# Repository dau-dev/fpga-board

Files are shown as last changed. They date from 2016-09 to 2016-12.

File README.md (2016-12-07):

# fpga-board
Based on the Xilinx AC701 and KC705 reference designs, this board was created to address the dearth of PCIe and DDR SODIMM capable board for less than $1000.

##Features
- Artix 7 FPGA (160k)
- 4GB DDR3 SODIMM
- 256MB Quad SPI Flash
- 8Kb IIC EEPROM
- SD Card Slot
- 2x 10/100/1000 Mbps Ethernet
- PCI Express 4 Lane
- Onboard JTAG
- Fixed Oscillator with differential 200MHz output
- User Programmable (IIC) Differential Oscillator (Range: 10MHz - 810 MHz, 156.250 MHz default)
- ATX Power 
- Half-Length PCI Card form factor

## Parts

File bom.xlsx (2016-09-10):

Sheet: Sheet2
Part | Value | Where?
R15 | 4.7k | U34 | 1/10W | 5%
C192 | 0.1uF | U34 | 25V | X5R
C30 | 0.1uF | U51 | 25V | X5R
R166 | 100 | U51 | 1/10W | 1%
L8 | Ferrite-220 | VDD_EPHYCLK | 2A
L9 | Ferrite-220 | GND_EPHYCLK | 2A
C190 | 0.01uF | VDD_EPHYCLK | 25V | X7R
C191 | 0.01uF | VDDA_EPHYCLK | 25V | X7R
C133 | 10uF | VDDA_EPHYCLK | 16V | X5R
R156 | 10 | VDD_EPHYCLK | 1/8W | 5%
C300 | 18pF | X3 | 50V | NPO
C301 | 18pF | X3 | 50V | NPO
R320 | 1.0M | X3 | 1/10W | 5%
R486 | 0 | U2 | 1/10W | 5%
R487 | 0 | U2 | 1/10W | 5%
R94 | 15 | U26 | 1/10W | 1%
R95 | 15 | U26 | 1/10W | 1%
R96 | 15 | U26 | 1/10W | 1%
C7 | 0.1uF | U19 | 25V | X5R
R429 | 15 | U67 | 1/10W | 1%
R430 | 15 | U67 | 1/10W | 1%
R19 | 4.7k | U67 | 1/10W | 5%
R21 | 4.7k | U67 | 1/10W | 5%
C18 | 0.1uF | U67 | 25V | X5R
R18 | 4.7k | U67 | 1/10W | 5%
R432 | 15 | U67 | 1/10W | 1%
R431 | 15 | U67 | 1/10W | 1%
R58 | 4.7k | U52 | 1/10W | 5%
R57 | 4.7k | U52 | 1/10W | 5%
R62 | 4.7k | U52 | 1/10W | 5%
R63 | 4.7k | U52 | 1/10W | 5%
R64 | 4.7k | U52 | 1/10W | 5%
R65 | 4.7k | U52 | 1/10W | 5%
R66 | 4.7k | U52 | 1/10W | 5%
R67 | 4.7k | U52 | 1/10W | 5%
R68 | 4.7k | U52 | 1/10W | 5%
R69 | 4.7k | U52 | 1/10W | 5%
R70 | 4.7k | U52 | 1/10W | 5%
R71 | 4.7k | U52 | 1/10W | 5%
R73 | 4.7k | U52 | 1/10W | 5%
R72 | 4.7k | U52 | 1/10W | 5%
C66 | 0.1uF | U52 | 25V | X5R
R54 | 4.7k | U52 | 1/10W | 5%
R55 | 4.7k | U52 | 1/10W | 5%
R244 | 4.7k | U52 | 1/10W | 5%
R59 | 4.7k | U52 | 1/10W | 5%
R60 | 4.7k | U52 | 1/10W | 5%
R61 | 4.7k | U52 | 1/10W | 5%
C1 | 0.1uF | U1 | 25V | X5R
C2 | 0.1uF | U1 | 25V | X5R
C163 | 100uF | U1 | 6.3 | X5R
R469 | 4.7k | U66
R306 | 261 | U66 | 1/10W | 1%
R307 | 261 | U66 | 1/10W | 1%
R396 | 261 | U1 | 1/10W | 1%
R339 | 1.21K | U1 | 1/10W | 1%
R338 | 1.21K | U1 | 1/10W | 1%
R337 | 1.21K | U1 | 1/10W | 1%
R83 | 4.7k | U1 | 1/10W | 5%
C462 | 0.1uF | U1 | 25V | X5R
C491 | 0.1uF | U1 | 25V | X5R
C463 | 0.1uF | U1 | 25V | X5R
C492 | 0.1uF | U1 | 25V | X5R
C158 | 100uF | U1 | 6.3 | X5R
C402 | 100uF | U1 | 6.3 | X5R
C461 | 0.1uF | U1 | 25V | X5R
C490 | 0.1uF | U1 | 25V | X5R
C157 | 100uF | U1 | 6.3 | X5R
R6 | 4.7k | J1 | 1/10W | 5%
R5 | 4.7k | J1 | 1/10W | 5%
R7 | 4.7k | J1 | 1/10W | 5%
R8 | 4.7k | J1 | 1/10W | 5%
C19 | 0.1uF | J1 | 25V | X5R
C17 | 0.1uF | J1 | 25V | X5R
C16 | 0.1uF | J1 | 25V | X5R
C15 | 0.1uF | J1 | 25V | X5R
C14 | 0.1uF | J1 | 25V | X5R
C13 | 0.1uF | J1 | 25V | X5R
C4 | 0.1uF | J1 | 25V | X5R
C3 | 0.1uF | J1 | 25V | X5R
C40 | 0.1uF | J1 | 25V | X5R
C39 | 0.1uF | J1 | 25V | X5R
C38 | 0.1uF | J1 | 25V | X5R
C37 | 0.1uF | J1 | 25V | X5R
C27 | 0.1uF | J1 | 25V | X5R
C26 | 0.1uF | J1 | 25V | X5R
C21 | 0.1uF | J1 | 25V | X5R
C20 | 0.1uF | J1 | 25V | X5R
C53 | 0.1uF | VTTDDR | 25V | X5R
C54 | 0.1uF | VTTDDR | 25V | X5R
C55 | 0.1uF | VTTDDR | 25V | X5R
C394 | 10uF | VTTDDR | 6.3V | X5R
C41 | 0.1uF | FPGA_1V5 | 25V | X5R
C42 | 0.1uF | FPGA_1V5 | 25V | X5R
C43 | 0.1uF | FPGA_1V5 | 25V | X5R
C393 | 10uF | FPGA_1V5 | 6.3V | X5R
C396 | 330uF | FPGA_1V5 | 10V | TANT
C51 | 0.1uF | VTTDDR | 25V | X5R
C50 | 0.1uF | VTTDDR | 25V | X5R
C46 | 0.1uF | VTTDDR | 25V | X5R
C392 | 10uF | VTTDDR | 6.3V | X5R
C386 | 0.01uF | VTTVREF | 25V | X7R
C155 | 100uF | U1 | 6.3 | X5R
R325 | 51.1K | U29 | 1/10W | 1%
R319 | 51.1K | U29 | 1/10W | 1%
R322 | 51.1K | U29 | 1/10W | 1%
R321 | 51.1K | U29 | 1/10W | 1%
R323 | 51.1K | U29 | 1/10W | 1%
R318 | 51.1K | U29 | 1/10W | 1%
R324 | 51.1K | U29 | 1/10W | 1%
R317 | 51.1K | U29 | 1/10W | 1%
C52 | 0.1uF | U29 | 25V | X5R
L12 | Ferrite-220 | VCC1V8
C400 | 4.7uF | VCC1V8_FILT | 10V | X5R
C90 | 0.1uF | VCC1V8_FILT | 25V | X5R
C398 | 4.7uF | VCC1V8_FILT | 10V
C86 | 0.1uF | VCC1V8_FILT | 25V
C87 | 0.1uF | VCC1V8_FILT | 25V
C85 | 0.1uF | VCC1V8_FILT | 25V
C84 | 0.1uF | VCC1V8_FILT | 25V
C88 | 0.1uF | VCC1V8_FILT | 25V
C83 | 0.1uF | VCC1V8_FILT | 25V
C397 | 4.7uF | VCC1V8_FILT | 10V
C81 | 0.1uF | VCC1V8_FILT | 25V
C82 | 0.1uF | VCC1V8_FILT | 25V
C80 | 0.1uF | VCC1V8_FILT | 25V
C79 | 0.1uF | VCC1V8_FILT | 25V
C89 | 0.1uF | VCC1V8_FILT | 25V
C64 | 0.1uF | VCC1V8_FILT | 25V
C403 | 4.7uF | VCC1V8 | 10V
C98 | 0.1uF | VCC1V8 | 25V
C99 | 0.1uF | VCC1V8 | 25V
C97 | 0.1uF | VCC1V8 | 25V
C96 | 0.1uF | VCC1V8 | 25V
C100 | 0.1uF | VCC1V8 | 25V
R271 | 1.00K | U12 | 1/16W
R274 | 1.00K | U12 | 1/16W
R272 | 1.00K | U12 | 1/16W
R273 | 1.00K | U12 | 1/16W
R2 | 4.7k | U12 | 1/10W
R291 | 4.99K | U12 | 1/10W
R1 | 4.7k | U12 | 1/10W
C56 | 0.1uF | U12 | 25V
C395 | 1000pF | U12 | 50V
R448 | 100 | U12 | 1/10W | 1%
R449 | 100 | U12 | 1/10W | 1%
R447 | 100 | U12 | 1/10W | 1%
R445 | 100 | U12 | 1/10W | 1%
R443 | 100 | U12 | 1/10W | 1%
R438 | 100 | U12 | 1/10W | 1%
R450 | 100 | U12 | 1/10W | 1%
R451 | 100 | U12 | 1/10W | 1%
R446 | 100 | U12 | 1/10W | 1%
R444 | 100 | U12 | 1/10W | 1%
R442 | 100 | U12 | 1/10W | 1%
R441 | 100 | U12 | 1/10W | 1%
R281 | 261 | U12 | 1/10W
R280 | 261 | U12 | 1/10W
R279 | 261 | U12 | 1/10W
C405 | 18pF | X1 | 50V | NPO
C406 | 18pF | X1 | 50V | NPO
C401 | 4.7k | U12 | 10V
C93 | 0.1uF | U12 | 25V
C94 | 0.1uF | U12 | 25V
C92 | 0.1uF | U12 | 25V
C91 | 0.1uF | U12 | 25V
C95 | 0.1uF | U12 | 25V
L10 | Ferrite-220 | X6
C281 | 330uF | X6 | 10V | TANT
C328 | 10uF | X6 | 16V | X5R
R167 | 100 | U24 | 1/10W | 1%
C33 | 0.1uF | U24 | 25V | X5R
C34 | 0.1uF | U24 | 25V | X5R
R292 | 4.7k | U24 | 1/10W | 5%
R4 | 4.7k | U24 | 1/10W | 5%
R16 | 4.7k | U24 | 1/10W | 5%
R490 | 0 | U24 | 1/10W | 5%
R491 | 0 | U24 | 1/10W | 5%
R488 | 0 | U24 | 1/10W | 5%
R489 | 0 | U24 | 1/10W | 5%
C173 | 1uF | SI5324_VCC | 25V | X5R
C35 | 0.1uF | SI5324_VCC | 25V | X5R
C36 | 0.1uF | SI5324_VCC | 25V | X5R
C156 | 100uF | U1 | 6.3 | X5R
C159 | 100uF | U1 | 6.3 | X5R
C57 | 0.1uF | U5 | 25V | X5R
C58 | 0.1uF | U5 | 25V | X5R

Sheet: Sheet3
Item# | Qty | Ref Des | Device | Package | Value | Voltage | Tolerance | Dielectric | Power | Manf | Manf P/N | Dist | Dist P/N | Alternate P/N
1 | 1 | B1 | Battery Slot |  | TS518FE-FL35E |  |  |  |  | SEIKO | TS518FE-FL35E | SEIKO | TS518FE-FL35E
2 | 174 | C1,C2,C3,C4,C7,C8,C13,C14,C15,C16,C17,C18,C19,C20,C21,C22,C23,C26,C27,C30,C33,C34,C35,C36,C37,C38,C39,C40,C41,C42,C43,C44,C45,C46,C47,C48,C49,C50,C51,C52,C53,C54,C55,C56,C57,C58,C59,C60,C61,C62,C63,C64,C66,C67,C68,C69,C70,C71,C72,C73,C74,C75,C76,C77,C78,C79,C80,C81,C82,C83,C84,C85,C86,C87,C88,C89,C90,C91,C92,C93,C94,C95,C96,C97,C98,C99,C100,C105,C106,C107,C108,C109,C110,C111,C112,C113,C116,C117,C118,C119,C120,C121,C122,C123,C124,C125,C126,C127,C128,C129,C130,C131,C132,C134,C135,C136,C137,C138,C139,C140,C141,C142,C143,C144,C145,C146,C147,C148,C149,C162,C164,C165,C166,C170,C171,C178,C180,C183,C187,C192,C193,C195,C239,C255,C264,C286,C295,C305,C311,C318,C320,C321,C322,C461,C472,C473,C480,C491,C492,C504,C505,C506,C507,C508,C509,C510,C511,C512,C516,C520,C526,C527,C528,C529 | Capacitor | 0402 | 0.1UF | 25V | 10% | X5R |  | Taiyo | TMK105BJ104KV-F | Digikey | 587-1456-2-ND
3 | 2 | C65,C252 | Capacitor | 0805 | 10UF | 10V | 10% | X5R |  | Murata | GRM219R61A106KE44D | Digikey | 490-4735-2-ND | GRM21BR61A106KE19L
4 | 7 | C101,C102,C103,C104,C462,C463,C490 | Capacitor | 0402 | 0.1UF | 25V | 10% | X5R |  | Taiyo | TMK105BJ104KV-F | Digikey | 587-1456-2-ND
5 | 2 | C114,C115 | Capacitor | 1206 | 22UF | 25V | 10% | X5R |  | Murata | GRM31CR61E226KE15L | Digikey | 490-5527-1-ND
6 | 20 | C133,C263,C265,C266,C267,C271,C328,C334,C335,C336,C337,C338,C339,C497,C498,C499,C500,C501,C502,C503 | Capacitor | 1206 | 10UF | 16V | 20% | X5R |  | TDK | C3216X5R1C106M | Digikey | 445-1426-2-ND
7 | 2 | C150,C151 | Capacitor | 0402 | 0.022UF | 10V | 10% | X5R |  | Kemet | C0402C223K8PACTU | Digikey | 399-3015-2-ND
8 | 34 | C152,C153,C353,C354,C355,C356,C357,C358,C359,C360,C361,C362,C363,C364,C365,C366,C371,C372,C373,C374,C376,C377,C378,C379,C380,C381,C387,C388,C389,C390,C391,C484,C485,C488 | Capacitor | 0402 | 4.7UF | 6.3V | 20% | X5R |  | TDK | C1005X5R0J475M | Mouser | 810-C1005X5R0J475M
9 | 14 | C154,C268,C269,C270,C395,C483,C493,C495,C496,C521,C523,C525,C553,C554 | Capacitor | 0402 | 1000PF | 50V | 10% | X7R |  | Panasonic | ECJ-0EB1H102K | Digikey | PCC1721TR-ND
10 | 17 | C155,C156,C157,C158,C159,C160,C161,C163,C317,C399,C402,C418,C421,C422,C517,C530,C531 | Capacitor | 1206 | 100UF | 6.3 | 20% | X5R |  | TAIYO YUDEN | JMK316BJ107ML-T | Digikey | 587-1963-2-ND
11 | 11 | C167,C168,C169,C173,C174,C175,C176,C177,C514,C515,C804 | Capacitor | 0603 | 1UF | 25V | 10% | X5R |  | MURATA | GRM188R61E105KA12D | Digikey | 490-3897-2-ND
12 | 11 | C172,C179,C182,C184,C185,C186,C253,C254,C262,C313,C513 | Capacitor | 1206 | 10UF | 25V | 20% | X5R |  | Taiyo | TMK316BJ106KL-T | Digikey | 587-1337-2-ND | GRM31CR61E106KA12L
13 | 61 | C181,C213,C214,C215,C216,C220,C221,C222,C223,C224,C225,C227,C229,C230,C240,C241,C242,C243,C244,C245,C246,C247,C248,C249,C250,C251,C256,C257,C258,C259,C260,C261,C272,C273,C274,C275,C276,C277,C278,C279,C280,C282,C283,C284,C285,C293,C294,C296,C307,C308,C309,C310,C312,C314,C315,C323,C324,C326,C327,C382,C383 | Capacitor | 1206 | 47UF | 25V | 10% | X5R |  | TDK | C3216X5R1E476M | Digikey | 445-8047-2-ND
14 | 38 | C188,C189,C190,C191,C201,C202,C203,C204,C205,C206,C207,C208,C209,C210,C211,C325,C386,C482,C518,C519,C532,C533,C534,C535,C536,C537,C538,C540,C541,C542,C543,C544,C545,C546,C547,C548,C549,C550 | Capacitor | 0402 | 0.01UF | 25V | 10% | X7R |  | Kemet | C0402C103K3RACTU | Digikey | 399-1278-2-ND
15 | 6 | C194,C196,C292,C319,C551,C552 | Capacitor | 0402 | 1UF | 16V | 10% | X5R |  | TDK | C1005X5R1C105K | Digikey | 445-4978-2-ND
16 | 5 | C197,C198,C199,C200,C212 | Capacitor | 1206 | 100UF | 6.3V | 20% | X5R |  | TAIYO YUDEN | JMK316BJ107ML-T | Digikey | 587-1963-2-ND
17 |  | C217,C218 | Capacitor | 0402 | DNP | DNP | DNP | DNP |  | NA | NA | DNP | DNP
18 | 1 | C219 | Capacitor | 2917 | 47UF | 25V | 20% | TANT_POLY |  | AVX | TCJD476M025R0100 | Digikey | 478-6638-2-ND
19 | 3 | C226,C228,C494 | Capacitor | 0805 | 4.7UF | 25V | 10% | X5R |  | Taiyo | TMK212BJ475KG-T | Digikey | 587-1782-2-ND
20 | 8 | C231,C232,C233,C234,C235,C236,C237,C238 | Capacitor | 0402 | 0.22UF | 16V | 10% | X5R |  | TDK | C1005X5R1C224K | Digikey | 445-4972-2-ND
21 | 2 | C281,C396 | Capacitor | TANT_D | 330UF | 10V | 10% | TANT |  | KEMET | T495D337K010ATE125 | Digikey | 399-3884-2-nd | TAJD337K010RNJ
22 | 10 | C287,C288,C289,C290,C291,C297,C298,C299,C302,C303 | Capacitor | 0805 | 47UF | 6.3V | 20% | X5R |  | Kemet | C0805C476M9PACTU | Digikey | 399-5506-2-ND | JMK212BJ476MG-T
23 | 4 | C300,C301,C405,C406 | Capacitor | 0402 | 18PF | 50V | 5% | NPO |  | Murata | GRM1555C1H180JZ01D | Digikey | 490-1281-2-ND | ECU-E1H180JCQ
24 | 9 | C304,C306,C384,C385,C474,C475,C478,C479,C481 | Capacitor | 1210 | 22UF | 25V | 10% | X5R |  | MURATA | GRM32ER61E226KE15L | Digikey | 490-3889-2-ND
25 |  | C329,C330,C331,C332,C333,C340,C341,C342,C343,C344,C345,C346,C347,C348,C349,C350,C351,C352 | Capacitor | C402_25 | DNP | 25V | 10% | X5R |  | TAIYO YUDEN | TMK105BJ104KV-F | DNP | DNP
26 | 5 | C367,C368,C369,C370,C375 | Capacitor | 0402 | 4.7UF | 6.3V | 20% | X5R |  | TDK | C1005X5R0J475M | Mouser | 810-C1005X5R0J475M
27 | 3 | C392,C393,C394 | Capacitor | 0805 | 10UF | 6.3V | 20% | X5R |  | Murata | GRM21BR60J106ME19L | Digikey | 490-1718-2-ND | ECJ-2FB0J106M
28 | 5 | C397,C398,C400,C401,C403 | Capacitor | 0603 | 4.7UF | 10V | 10% | X5R |  | TAIYO | LMK107BJ475KA-T | Digikey | 587-1441-2-ND | C1608X5R1A475K
29 | 1 | C407 | Capacitor | TANT_E | 680UF | 6.3V | 10% | TANT |  | AVX | TAJE687K006RNJ | Digikey | 478-2349-2-ND
30 | 48 | C408,C409,C410,C411,C412,C413,C414,C415,C416,C417,C419,C420,C425,C428,C429,C430,C431,C432,C434,C435,C436,C437,C438,C439,C440,C441,C442,C443,C445,C446,C447,C450,C451,C454,C455,C456,C457,C458,C459,C460,C464,C465,C466,C467,C468,C469,C470,C471 | Capacitor | 0402 | 0.47UF | 10V | 10% | X5R |  | Murata | GRM155R61A474KE15D | Digikey | 490-3264-1-ND
31 | 2 | C423,C424 | Capacitor | 0402 | 10PF | 50V | 5% | NP0 |  | Panasonic | ECJ-0EC1H100D | Digikey | PCC100CQTR-ND
32 | 8 | C426,C427,C433,C444,C448,C449,C452,C453 | Capacitor | 0402 | 0.47uF | 10V | 10% | X5R |  | Murata | GRM155R61A474KE15D | Digikey | 490-3264-1-ND
33 | 1 | C489 | Capacitor | 0402 | 2200PF | 25V | 10% | X7R |  | KEMET | C0402C222K3RACTU | Digikey | 399-1033-1-ND
34 | 2 | C486,C487 | Capacitor | 0805 | 100PF | 500V | 5% | NP0 |  | KEMET | C0805C101JCGACTU | Digikey | 399-5102-2-ND
35 | 2 | C522,C524 | Capacitor | 0402 | 3300PF | 25V | 10% | X7R |  | Panasonic | ECJ-0EB1E332K | Digikey | PCC332BQCT-ND
36 | 1 | C539 | Capacitor | CAP_F | 330UF | 25V | 20% | ELEC |  | Panasonic | EEE-FK1E331P | Digikey | PCE3803TR-ND
37 | 2 | C555,C556 | Capacitor | 0805 | 100UF | 6.3V | 20% | TANT |  | AVX | TLJP107M006R5400 | Digikey | 478-5260-2-ND
38 |  | CBL1 | PCIE Adapter Cable | MECH_PCIE_ADAPTER_CABLE | DNP |  |  |  |  | ANY | ANY | ANY | ANY
39 | 0 | CBL2 | Cable |  | PC_POWER_CABLE |  |  |  |  | AdamTech | PC-0102060AC03 | Mouser | 737-PC-0102060AC03
40 | 0 | CBL3 | Cable |  | USB_MINIB_CABLE |  |  |  |  | Qualtek | 3021009-06 | Mouser | 562-3021009-06
41 | 0 | CBL4 | Cable |  | USB_MICRO_CABLE |  |  |  |  | ASSMANN | AK67421-2-R | Digikey | AE10342-ND
42 | 1 | CG1 | I/O Cage | 74754-0101 | 74754-0101 |  |  |  |  | MOLEX | 74754-0101 | MOLEX | 74754-0101
43 | 9 | CP1,CP2,CP3,CP4,CP5,CP6,CP7,CP8,CP9 | Capacitor Array | 0805_A4 | 0.1UF | 10V | 20% | X5R |  | PANASONIC-ECG | ECJ-TVB1A104M | Digikey | 587-1046-2-ND
44 | 5 | D1,D2,D3,D4,D7 | Diode | DIO_CASE017AA_01 | 1N5335BRLG | 3.9V |  |  | 320MA | ON SEMICONDUCTOR | 1N5335BRLG | Digikey | 1N5335BRLGOSCT-ND
45 | 1 | D5 | Diode | DIO_DFS1150_7 | DFLS1150 | 820MV |  |  |  | Diodes Inc | DFLS1150-7 | Digikey | DFLS1150DICT-ND
46 | 1 | D6 | Diode | SOT_23 | BAS40-04 | 40V |  |  | 200MW | MICRO COMMERCIAL | BAS40-04-TP | Digikey | BAS40-04TPMSCT-ND
47 | 1 | D14 | Diode | MINIMELF | DL4148 | 100V |  |  | 460MW | MCC | DL4148-TP | Digikey | DL4148-TPMSCT-ND
48 | 1 | D15 | Diode | SOD_323F_REV | MM3Z2V7B | 2.7V | 2% |  | 460MW | Fairchild | MM3Z2V7B | Digikey | MM3Z2V7BCT-ND
49 | 1 | DIMMCAGE1 | SODIMM_CAGE |  | SODIMM_CAGE |  |  |  |  | LEADER TECH | 20S-CBSFNSV-1.50X3.0X0.35 | LEADER TECH | 20S-CBSFNSV-1.50X3.0X0.35
50 | 4 | DP1,DP2,DP3,DP4 | Diode | RCLAMP0524P | RCLAMP0524P | 15V |  | DIEL |  | Semtech | RCLAMP0524P.TCT | Digikey | RCLAMP0524PCT-ND
51 | 1 | DS1 | LED |  | LED-GRN-RED | 2.0V |  |  | 2.0-20MA | AVAGO | HSMF-C155 | Digikey | 516-1456-1-ND
52 | 14 | DS2,DS3,DS4,DS5,DS6,DS10,DS11,DS12,DS13,DS14,DS20,DS22,DS23,DS27 | LED |  | LED-GRN-SMT | 2.2V |  |  | 2.2-20MA | Lumex | SML-LX0603GW-TR | Digikey | 67-1549-2-ND
53 | 9 | DS15,DS16,DS17,DS18,DS19,DS21,DS24,DS25,DS26 | LED |  | LED-GRN-SMT | 2.2V |  |  |  | LUMEX | SML-LX0603GW | Digikey | 67-1549-2-ND
54 | 1 | J1 | Connector |  | DDR3_SO-DIMM_SHIELDED |  |  |  |  | Foxconn | AS0A626-U2SN-7F | Foxconn | AS0A626-U2SN-7F
55 | 1 | J2 | Connector | 2X5 | HDR_BOX_2X5 |  |  |  |  | Assmann | AWHW10G-0202-T-R | Digikey | HRP10H-ND
56 | 10 | J3,J5,J6,J8,J9,J10,J11,J52,J53,J63 | Header | 1X2 | HDR_1X2 |  |  |  |  | Sullins | PBC36SAAN | Digikey | S1011E-36-ND
57 | 1 | J4 | Connector |  | 87832-1420 |  |  |  |  | Molex | 87832-1420 | Digikey | WM18641-ND
58 | 1 | J7 | Header | 1X9 | HDR_1X9 |  |  |  |  | Sullins | PBC36SAAN | Digikey | S1011E-36-ND
59 | 1 | J12 | Header | 2X2 | HDR_2X2 |  |  |  |  | Sullins | PBC36DAAN | Digikey | S2011E-36-ND
60 | 1 | J17 | Connector |  | CONN_USB_MINI_B_TH |  |  |  |  | Molex | 54819-0589 | Mouser | 538-54819-0589
61 | 1 | J19 | Connector |  | TST-110-01-G-D |  |  |  |  | Samtec | TST-110-01-G-D | Samtec | TST-110-01-G-D
62 | 3 | J20,J21,J22 | Header | 1X1 | HDR_1X1 |  |  |  |  | Sullins | PBC36SAAN | Digikey | S1011E-36-ND
63 | 1 | J23 | Header | 2X7 | HDR_2X7 |  |  |  |  | Samtec | MTLW-107-07-G-D-265 | Digikey | S2011E-36-ND
64 |  | J24 | Header | 1X2 | DNP |  |  |  |  | SULLINS | PBC36SAAN | DNP | DNP
65 | 10 | J25,J26,J31,J32,J33,J34,J44,J45,J46,J47 | Connector |  | 32K10K-400L5 |  |  |  |  | Rosenberger | 32K10K-400L5 | Rosenberger | 32K10K-400L5
66 | 2 | J28,J29 | Test Points |  | BLACK |  |  |  |  | Keystone | 5001 | Digikey | 5001K-ND
67 | 1 | J30 | Connector |  | ASP_134486_01 |  |  |  |  | Samtec | ASP_134486_01 | Samtec | ASP-134486-01
68 | 8 | J35,J36,J37,J38,J39,J42,J43,J54 | Header | 1X3 | HDR_1X3 |  |  |  |  | Sullins | PBC36SAAN | Digikey | S1011E-36-ND
69 | 2 | J40,J41 | Test Points |  | YELLOW |  |  |  |  | Keystone | 5004 | Digikey | 5004K-ND
70 | 1 | J48 | Header | 1X6 | HDR_1X6 |  |  |  |  | Sullins | PBC36SAAN | Digikey | S1011E-36-ND
71 | 1 | J49 | Connector |  | 39-30-1060 |  |  |  |  | Molex | 39-30-1060 | Digikey | WM1353-ND
72 | 1 | J61 | Connector |  | 22_11_2032 |  |  |  |  | Molex | 22-11-2032 | Digikey | WM2701-ND
73 | 5 | L1,L2,L3,L4,L5 | Ferrite Chip | 0805 |  |  |  |  |  | Laird | HZ0805E601R-10 | Digikey | 240-2399-2-ND
74 | 2 | L6,L7 | Inductor | IND_IHLP2020BZ_ER |  |  |  |  |  | Vishay | IHLP2020BZER4R7M11 | Digikey | 541-1222-1-ND
75 | 15 | L8,L9,L10,L11,L12,L13,L14,L15,L16,L17,L18,L19,L20,L21,L22 | Ferrite Chip | 0603 |  |  |  |  |  | TDK | MPZ1608S221A | Digikey | 445-1565-2-ND
76 | 9 | L24,L25,L26,L27,L28,L29,L30,L31,L32 | Inductor | 2773021447 |  |  |  |  |  | FAIR-RITE | 2773021447 | Mouser | 623-2773021447LF
77 | 1 | LCD1 | Display |  | LCD_DISPLAY_16X2 |  |  |  |  | DisplayTech | S162D BA BC | DisplayTech | S162D BA BC
78 | 1 | LCD1_J11 | Connector | SAMTEC_SLW_107_01_G_D | SLW-107-01-G-D |  |  |  |  | Samtec | SLW-107-01-G-D | Samtec | SLW-107-01-G-D
79 |  | MH1,MH2,MH3,MH4,MH5,MH6 | Mounting Hole |  | DNP |  |  |  |  | DNP | DNP | DNP | DNP
80 |  | MH7,MH8,MH9 | Mounting Hole |  | DNP |  |  |  |  | DNP | DNP | DNP | DNP
81 | 15 | MJB1,MJB2,MJB3,MJB4,MJB5,MJB6,MJB7,MJB8,MJB9,MJB10,MJB11,MJB12,MJB13,MJB14,MJB15 | Shunt |  | JUMPER_BLOCK_2-PIN |  |  |  |  | ADAMTECH | MSDA-G | Digikey | S9002-ND
82 | 1 | MMD1 | Memory | DDR3_SODIMM | DDR3_SODIMM |  |  |  |  | MICRON | MT8JTF12864HZ-1G6G1 | Edge | MT8JTF12864HZ-1G6G1
83 | 6 | MRB1,MRB2,MRB3,MRB4,MRB5,MRB6 | Bumper |  | RUBBER_BUMPER |  |  |  |  | Keystone | 720 | Digikey | 720K-ND
84 | 12 | MS1,MS2,MS3,MS4,MS5,MS6,MS13,MS14,MS15,MS16,MS17,MS18 | Screws |  | MACHINE_SCREW_4-40 |  |  |  |  | ANY | ANY | ANY | ANY
85 | 6 | MS7,MS8,MS9,MS10,MS11,MS12 | Screw |  | MACHINE_SCREW_M2_5 |  |  |  |  | Olander | 25S5PPMS | Olander | 25S5PPMS
86 | 3 | MSO1,MSO2,MSO3 | Standoff |  | STANDOFF_0P375 |  |  |  |  | Keystone | 1892 | Digikey | 1892K-ND
87 | 3 | MSO4,MSO5,MSO6 | Standoff |  | STANDOFF_0P375 |  |  |  |  | Keystone | 1892 | Digikey | 1892K-ND
88 | 3 | MSO7,MSO8,MSO9 | Standoff |  | STANDOFF_10MM |  |  |  |  | Olander | 25S10H4FU | Olander | 25S10H4FU/LL
89 | 1 | MSTK1 | PCIE_POWER_STICKER | PCIE_POWER_STICKER | PCIE_POWER_STICKER |  |  |  |  | XILINX | 250446 | XILINX | 250446
90 | 1 | P1 | PCIE_4LANE_EDGE | PCIE_4LANE_EDGE | PCIE_4LANE_EDGE |  |  |  |  | N/A | N/A
91 | 1 | P2 | Connector | CON23_MOLEX_HDMI_RA | 500254-1927 |  |  |  |  | Molex | 500254-1927 | Molex | 500254-1927
92 | 1 | P3 | Connector | CON_MOL_20P_74441_0010 | 74441-0010 |  |  |  |  | Molex | 74441-0010 | Molex | 74441-0010
93 | 1 | P4 | Socket | RJ45_HFJ11_1G01E | RJ45 |  |  |  |  | Halo | HFJ11-1G01ERL | Halo | HFJ11-1G01ERL
94 | 0 | PB1 | PWR_BRICK_12V |  | PWR_BRICK_12V |  |  |  |  | LTE | LTE60E-S2-1
95 | 1 | PL1 | Mechanical |  |  |  |  |  |  | PURCELL | P1155-0003 | PURCELL | P1155-0003
96 | 20 | Q1,Q2,Q3,Q4,Q5,Q6,Q7,Q8,Q9,Q10,Q11,Q12,Q13,Q14,Q15,Q16,Q18,Q19,Q20,Q21 | Mosfet | SOT_23 | NDS331N | 20V |  |  | 460MW | Fairchild | NDS331N | Digikey | NDS331NTR-ND
97 | 1 | Q17 | Mosfet | SOT_223 | NDT3055L | 60V |  |  | 1.3W | Fairchild | NDT3055L | Digikey | NDT3055LCT-ND
98 | 4 | Q22,Q23,Q24,Q25 | Transistor | SOT_23 | NDS336P | 20V |  |  | 460MW | FAIRCHILD | NDS336P | Digikey | NDS336P
99 | 2 | R1,R2 | Resistor | 0402 | 4.7K |  | 5% |  | 1/10W | Panasonic | ERJ-2GEJ472X | Digikey | P4.7KJTR-ND
100 |  | R3,R10 | Resistor | 0402 | DNP |  | 5% |  | 1/10W | PANASONIC | ERJ-2GEJ472X | DNP | DNP
101 | 55 | R4,R5,R6,R7,R8,R9,R11,R12,R13,R14,R15,R16,R18,R19,R21,R32,R36,R37,R38,R39,R40,R41,R42,R43,R44,R45,R50,R51,R52,R53,R54,R55,R57,R58,R59,R60,R61,R62,R63,R64,R65,R66,R67,R68,R69,R70,R71,R72,R73,R83,R244,R292,R391,R392,R469 | Resistor | 0402 | 4.7K |  | 5% |  | 1/10W | Panasonic | ERJ-2GEJ472X | Digikey | P4.7KJTR-ND
102 |  | R17,R20,R56,R233,R234,R235,R236,R241,R242,R243,R357,R439,R440 | Resistor | 0402 | DNP |  | DNP |  | DNP | DNP | DNP | DNP | DNP
103 | 12 | R22,R23,R24,R25,R26,R28,R29,R46,R330,R413,R466,R483 | Resistor | 0402 | 4.7K |  | 5% |  | 1/16W | PANASONIC - SCD | ERJ-2GEJ472X | Digikey | P4.7KJTR-ND
104 | 1 | R27 | Resistor | 0402 | 1.13K |  | 1% |  | 1/10W | PANASONIC ECG | ERJ-2RKF1131X | Digikey | P1.13KLTR-ND
105 | 1 | R30 | Resistor | 0402 | 2.55K |  | 1% |  | 1/16W | Vishay | CRCW04022K55FKED | Digikey | 541-2.55KLTR-ND
106 | 2 | R31,R34 | Resistor | 0402 | 1.50K |  | 1% |  | 1/10W | Panasonic | ERJ-2RKF1501X | Digikey | P1.50KLTR-ND
107 | 2 | R33,R204 | Resistor | 0402 | 453 |  | 1% |  | 1/10W | PANASONIC ECG | ERJ-2RKF4530X | Digikey | P453LTR-ND
108 | 3 | R35,R47,R197 | Resistor | 0402 | 806 |  | 1% |  | 1/10W | PANASONIC ECG | ERJ-2RKF8060X | Digikey | P806LTR-ND
109 | 1 | R48 | Resistor | 0402 | 750 |  | 1% |  | 1/10W | PANASONIC ECG | ERJ-2RKF7500X | Digikey | P750LTR-ND
110 | 1 | R49 | Resistor | 0402 | 374 |  | 1% |  | 1/10W | PANASONIC ECG | ERJ-2RKF3740X | Digikey | P374LTR-ND
111 | 29 | R74,R75,R122,R123,R124,R125,R126,R127,R128,R129,R130,R131,R132,R137,R138,R140,R141,R401,R402,R404,R405,R406,R407,R408,R414,R415,R416,R417,R418 | Resistor | 0402 | 10 |  | 1% |  | 1/10W | Panasonic | ERJ-2RKF10R0X | Digikey | P10.0LTR-ND
112 |  | R76,R77,R78,R79,R80,R81,R82,R85,R86,R87,R90,R91,R92,R93,R98,R99,R100,R101,R109,R110,R111,R112,R113,R114,R115,R116,R117,R119,R120,R121,R133,R134,R135,R136,R139,R142,R143,R144,R145,R146,R155,R157,R158,R159,R160,R161,R162,R163,R164,R168,R169,R170,R171,R172,R173,R174,R175,R176,R177,R178,R179,R180,R181,R182 | Resistor | 0201 | DNP |  | 1% |  | 1/20W | PANASONIC-ECG | ERJ-1GEF49R9C | DNP | DNP
113 | 37 | R84,R151,R152,R192,R193,R196,R245,R247,R248,R250,R252,R256,R258,R260,R297,R332,R333,R374,R375,R376,R377,R379,R380,R381,R382,R384,R386,R387,R388,R393,R394,R452,R453,R454,R455,R481,R482 | Resistor | 0402 | 10.0K |  | 1% |  | 1/10W | Panasonic | ERJ-2RKF1002X | Digikey | P10.0KLTR-ND
114 | 2 | R88,R89 | Resistor | 0201 | 49.9 |  | 1% |  | 1/20W | Vishay | CRCW020149R9FKED | Digikey | 541-49.9AABTR-ND | ERJ-1GEF49R9C
115 | 8 | R94,R95,R96,R97,R429,R430,R431,R432 | Resistor | 0402 | 15 |  | 1% |  | 1/10W | Panasonic | ERJ-2RKF15R0X | Digikey | P15.0LTR-ND
116 | 1 | R102 | Resistor | 0402 | 887 |  | 1% |  | 1/10W | Panasonic | ERJ-2RKF8870X | Digikey | P887LTR-ND
117 | 1 | R103 | Resistor | 0402 | 27.4K |  | 1% |  | 1/10W | Panasonic | ERJ-2RKF2742X | Digikey | P27.4KLTR-ND
118 | 5 | R104,R105,R106,R107,R108 | Resistor | 0402 | 2.43K |  | 1% |  | 1/10W | Panasonic | ERJ-2RKF2431X | Digikey | P2.43KLTR-ND
119 | 1 | R118 | Resistor | 0402 | 6.81K |  | 1% |  | 1/10W | Panasonic | ERJ-2RKF6811X | Digikey | P6.81KLTR-ND
120 | 14 | R147,R148,R149,R150,R153,R154,R184,R185,R186,R187,R188,R189,R311,R312 | Resistor | 0402 | 49.9 |  | 1% |  | 1/10W | Panasonic | ERJ-2RKF49R9X | Digikey | P49.9LTR-ND
121 | 1 | R156 | Resistor | 0805 | 10 |  | 5% |  | 1/8W | Panasonic | ERJ-6GEYJ100V | Digikey | P10ATR-ND
122 | 24 | R165,R167,R364,R365,R366,R367,R368,R370,R371,R372,R373,R389,R438,R441,R442,R443,R444,R445,R446,R447,R448,R449,R450,R451 | Resistor | 0402 | 100 |  | 1% |  | 1/10W | Panasonic | ERJ-2RKF1000X | Digikey | P100LTR-ND
123 | 1 | R166 | Resistor | 0402 | 100 |  | 1% |  | 1/10W | Panasonic | ERJ-2RKF1000X | Digikey | P100LTR-ND
124 | 1 | R183 | Resistor | 3637_SMT | 0.005R |  | 0.1% |  | 3W | Vishay | Y14880R00500B9R | Digikey | Y1488-.005BTR-ND
125 | 8 | R190,R191,R194,R195,R198,R199,R200,R205 | Resistor | 1224_SMT | 0.005 |  | 1% |  | 2W | OHMITE | LVK25R005FER | Digikey | LVK25R005FERTR-ND
126 | 2 | R201,R435 | Resistor | 0402 | 715 |  | 1% |  | 1/10W | PANASONIC ECG | ERJ-2RKF7150X | Digikey | P715LTR-ND
127 | 2 | R202,R208 | Resistor | 0402 | 5.76K |  | 1% |  | 1/10W | PANASONIC ECG | ERJ-2RKF5761X | Digikey | P5.76KLTR-ND
128 | 1 | R203 | Resistor | 0402 | 953 |  | 1% |  | 1/10W | PANASONIC ECG | ERJ-2RKF9530X | Digikey | P953LTR-ND
129 | 2 | R206,R434 | Resistor | 0402 | 316 |  | 1% |  | 1/10W | PANASONIC ECG | ERJ-2RKF3160X | Digikey | P316LTR-ND
130 | 1 | R207 | Resistor | 0402 | 2.87K |  | 1% |  | 1/10W | Panasonic | ERJ-2RKF2871X | Digikey | P2.87KLTR-ND
131 | 1 | R209 | Resistor | 0402 | 1.69K |  | 1% |  | 1/10W | PANASONIC ECG | ERJ-2RKF1691X | Digikey | P1.69KLTR-ND
132 | 9 | R210,R211,R310,R313,R314,R315,R316,R385,R468 | Resistor | 0402 | 2.00K |  | 1% |  | 1/16W | Panasonic | ERJ-S02F2001X | Digikey | ERJ-S02F2001X-ND
133 |  | R212,R213,R214,R215,R216,R217,R218,R219,R220,R221,R222,R223,R224,R225,R226,R227 | Resistor | C402_25 | DNP |  | 1% |  | 1/10W | PANASONIC | ERJ-2RKF49R9X | DNP | DNP
134 |  | R228,R229,R230,R231,R237,R238,R239,R240 | Resistor | C402_25 | DNP |  | 1% |  | 1/10W | PANASONIC | ERJ-2RKF1000X | DNP | DNP
135 | 1 | R232 | Resistor | POT_3352W | 2K |  | 20% |  | 1/2W | Bourns | 3352W-1-202LF | Digikey | 3352W-202LF-ND
136 | 1 | R246 | Resistor | 0402 | 6.49K |  | 1% |  | 1/10W | PANASONIC ECG | ERJ-2RKF6491X | Digikey | P6.49KLTR-ND
137 | 3 | R249,R294,R326 | Resistor | 0402 | 3.01K |  | 1% |  | 1/10W | Panasonic | ERJ-2RKF3011X | Digikey | P3.01KLTR-ND
138 | 5 | R251,R253,R257,R302,R436 | Resistor | 0402 | 200K |  | 1% |  | 1/10W | Panasonic | ERJ-2RKF2003X | Digikey | P200KLTR-ND
139 | 36 | R254,R255,R265,R270,R271,R272,R273,R274,R277,R278,R295,R296,R341,R342,R343,R344,R345,R346,R347,R348,R349,R350,R352,R383,R433,R470,R471,R472,R473,R474,R475,R476,R477,R478,R479,R480 | Resistor | 0402 | 1.00K |  | 1% |  | 1/16W | ROHM | MCR01MZPF1001 | Digikey | RHM1.00KLTR-ND
140 |  | R259,R465 | Resistor | 0402 | DNP |  | 1% |  | 1/10W | PANASONIC ECG | ERJ-2RKF2613X | DNP | DNP
141 | 14 | R261,R360,R484,R485,R486,R487,R488,R489,R490,R491,R492,R493,R494,R495 | Resistor | 0402 | 0 |  | 5% |  | 1/10W | Panasonic | ERJ-2GE0R00X | Digikey | P0.0JTR-ND
142 | 2 | R262,R303 | Resistor | 0402 | 324K |  | 1% |  | 1/10W | PANASONIC ECG | ERJ-2RKF3243X | Digikey | P324KLTR-ND
143 | 5 | R263,R267,R268,R269,R334 | Resistor | 0402 | 2.05K |  | 1% |  | 1/10W | Panasonic | ERJ-2RKF2051X | Digikey | P2.05KLTR-ND
144 | 1 | R264 | Resistor | 0402 | 3.40K |  | 1% |  | 1/10W | PANASONIC ECG | ERJ-2RKF3401X | Digikey | P3.40KLTR-ND
145 | 1 | R266 | Resistor | 0402 | 5.23K |  | 1% |  | 1/16W | Vishay | CRCW04025K23FKED | Digikey | 541-5.23KLTR-ND
146 |  | R275 | Resistor | 0402 | DNP |  | 1% |  | 1/16W | DNP | DNP | DNP | DNP
147 | 1 | R276 | Resistor | 0402 | 649 |  | 1% |  | 1/10W | PANASONIC ECG | ERJ-2RKF6490X | Digikey | P649LTR-ND
148 | 20 | R279,R280,R281,R282,R283,R284,R285,R286,R287,R288,R289,R290,R304,R305,R306,R307,R378,R396,R419,R428 | Resistor | 0402 | 261 |  | 1% |  | 1/10W | Panasonic | ERJ-2RKF2610X | Digikey | P261LTR-ND
149 | 1 | R291 | Resistor | 0402 | 4.99K |  | 1% |  | 1/10W | Panasonic | ERJ-2RKF4991X | Digikey | P4.99KLTR-ND
150 | 1 | R293 | Resistor | 0402 | 2.7K |  | 1% |  | 1/10W | Panasonic | ERJ-2RKF2701X | Digikey | P2.70KLCT-ND
151 | 5 | R298,R299,R300,R301,R340 | Resistor | 0402 | 100K |  | 1% |  | 1/10W | Panasonic | ERJ-2RKF1003X | Digikey | P100KLTR-ND
152 | 2 | R308,R425 | Resistor | 0402 | 1.78K |  | 1% |  | 1/10W | PANASONIC ECG | ERJ-2RKF1781X | Digikey | P1.78KLTR-ND
153 | 2 | R309,R369 | Resistor | 0402 | 2.15K |  | 1% |  | 1/10W | Panasonic | ERJ-2RKF2151X | Digikey | P2.15KLTR-ND
154 | 8 | R317,R318,R319,R321,R322,R323,R324,R325 | Resistor | 0402 | 51.1K |  | 1% |  | 1/10W | Panasonic | ERJ-2RKF5112X | Digikey | P51.1KLCT-ND
155 | 1 | R320 | Resistor | 0402 | 1.0M |  | 5% |  | 1/10W | Panasonic | ERJ-2GEJ105X | Digikey | P1.0MJTR-ND
156 | 1 | R327 | Resistor | 0402 | 53.6K |  | 1% |  | 1/10W | Panasonic | ERJ-2RKF5362X | Digikey | P53.6KLTR-ND
157 | 2 | R328,R329 | Resistor | 0402 | 90.9K |  | 1% |  | 1/10W | PANASONIC ECG | ERJ-2RKF9092X | Digikey | P90.9KLTR-ND
158 | 1 | R331 | Resistor | 0402 | 649 |  | 1% |  | 1/10W | PANASONIC ECG | ERJ-2RKF6490X | Digikey | P649LTR-ND
159 | 1 | R335 | Resistor | 0402 | 5.62K |  | 1% |  | 1/10W | Panasonic | ERJ-2RKF5621X | Digikey | P5.62KLTR-ND
160 | 1 | R336 | Resistor | 0402 | 1.07K |  | 1% |  | 1/16W | Vishay | CRCW04021K07FKED | Digikey | 541-1.07KLTR-ND
161 | 3 | R337,R338,R339 | Resistor | 0402 | 1.21K |  | 1% |  | 1/10W | Panasonic | ERJ-2RKF1211X | Digikey | P1.21KLTR-ND
162 | 1 | R351 | Resistor | 0402 | 41.2K |  | 1% |  | 1/10W | PANASONIC ECG | ERJ-2RKF4122X | Digikey | P41.2KLTR-ND
163 | 9 | R353,R354,R355,R356,R358,R359,R361,R362,R363 | Resistor | 0402 | 9.76K |  | 1% |  | 1/10W | PANASONIC ECG | ERJ-2RKF9761X | Digikey | P9.76KLTR-ND
164 | 1 | R390 | Resistor | 0402 | 4.75K |  | 1% |  | 1/10W | Panasonic | ERJ-2RKF4751X | Digikey | P4.75KLTR-ND
165 | 1 | R395 | Resistor | 0402 | 4.64K |  | 1% |  | 1/10W | PANASONIC ECG | ERJ-2RKF4641X | Digikey | P4.64KLTR-ND
166 | 1 | R397 | Resistor | 0402 | 1.58K |  | 1% |  | 1/10W | Panasonic | ERJ-2RKF1581X | Digikey | P1.58KLTR-ND
167 | 1 | R398 | Resistor | 0402 | 1.96K |  | 1% |  | 1/10W | Panasonic | ERJ-2RKF1961X | Digikey | P1.96KLTR-ND
168 | 3 | R399,R410,R422 | Resistor | 0402 | 3.74K |  | 1% |  | 1/10W | Panasonic | ERJ-2RKF3741X | Digikey | P3.74KLTR-ND
169 | 1 | R400 | Resistor | 0402 | 9.09K |  | 1% |  | 1/10W | Panasonic | ERJ-2RKF9091X | Digikey | P9.09KLTR-ND
170 | 1 | R403 | Resistor | 0402 | 1.10K |  | 1% |  | 1/10W | PANASONIC-ECG | ERJ-2RKF1101X | Digikey | P1.10KLTR-ND
171 | 1 | R409 | Resistor | 0402 | 2.37K |  | 1% |  | 1/10W | Panasonic | ERJ-2RKF2371X | Digikey | P2.37KLTR-ND
172 | 1 | R411 | Resistor | 0402 | 931 |  | 1% |  | 1/10W | PANASONIC ECG | ERJ-2RKF9310X | Digikey | P931LTR-ND
173 | 3 | R412,R420,R467 | Resistor | 0402 | 3.16K |  | 1% |  | 1/10W | PANASONIC ECG | ERJ-2RKF3161X | Digikey | P3.16KLTR-ND
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

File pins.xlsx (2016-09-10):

No. | Part Pin | Pin Name | Net | FPGA Pin | Part
1 | 1 | Vrefdq | VTTVREF |  | J1
2 | 3 | Vss | GND |  | J1
3 | 5 | DQ0 | D_D0 |  | J1
4 | 7 | DQ1 | D_D1 |  | J1
5 | 9 | Vss | GND |  | J1
6 | 11 | DM0 | D_DM0 |  | J1
7 | 13 | Vss | GND |  | J1
8 | 15 | DQ2 | D_D2 |  | J1
9 | 17 | DQ3 | D_D3 |  | J1
10 | 19 | Vss | GND |  | J1
11 | 21 | DQ8 | D_D8 |  | J1
12 | 23 | DQ9 | D_D9 |  | J1
13 | 25 | Vss | GND |  | J1
14 | 27 | DQS1_N | D_DQS1_N |  | J1
15 | 29 | DQS1_P | D_DQS1_P |  | J1
16 | 31 | Vss | GND |  | J1
17 | 33 | DQ10 | D_D10 |  | J1
18 | 35 | DQ11 | D_D11 |  | J1
19 | 37 | Vss | GND |  | J1
20 | 39 | DQ16 | D_D16 |  | J1
21 | 41 | DQ17 | D_D17 |  | J1
22 | 43 | Vss | GND |  | J1
23 | 45 | DQS2_N | D_DQS2_N |  | J1
24 | 47 | DQS2_P | D_DQS2_P |  | J1
25 | 49 | Vss | GND |  | J1
26 | 51 | DQ18 | D_D18 |  | J1
27 | 53 | DQ19 | D_D19 |  | J1
28 | 55 | Vss | GND |  | J1
29 | 57 | DQ24 | D_D24 |  | J1
30 | 59 | DQ25 | D_D25 |  | J1
31 | 61 | Vss | GND |  | J1
32 | 63 | DM3 | D_DM3 |  | J1
33 | 65 | Vss | GND |  | J1
34 | 67 | DQ26 | D_D26 |  | J1
35 | 69 | DQ27 | D_D27 |  | J1
36 | 71 | Vss | GND |  | J1
37 | 73 | CKE0 | D_CKE0 |  | J1
38 | 75 | Vdd | VCC1V5_F |  | J1
39 | 77 | NC | NC |  | J1
40 | 79 | BA2 | D_BA2 |  | J1
41 | 81 | Vdd | VCC1V5_F |  | J1
42 | 83 | A12 | D_A12 |  | J1
43 | 85 | A9 | D_A9 |  | J1
44 | 87 | Vdd | VCC1V5_F |  | J1
45 | 89 | A8 | D_A8 |  | J1
46 | 91 | A5 | D_A5 |  | J1
47 | 93 | Vdd | VCC1V5_F |  | J1
48 | 95 | A3 | D_A3 |  | J1
49 | 97 | A1 | D_A1 |  | J1
50 | 99 | Vdd | VCC1V5_F |  | J1
51 | 101 | CK0_P | D_CLK0_P |  | J1
52 | 103 | CK0_N | D_CLK0_N |  | J1
53 | 105 | Vdd | VCC1V5_F |  | J1
54 | 107 | A10 | D_A10 |  | J1
55 | 109 | BA0 | D_BA0 |  | J1
56 | 111 | Vdd | VCC1V5_F |  | J1
57 | 113 | WE_N | D_WE_N |  | J1
58 | 115 | CAS_N | D_CAS_N |  | J1
59 | 117 | Vdd | VCC1V5_F |  | J1
60 | 119 | A13 | D_A13 |  | J1
61 | 121 | S1_N | D_S1_N |  | J1
62 | 123 | Vdd | VCC1V5_F |  | J1
63 | 125 | TEST | NC |  | J1
64 | 127 | Vss | GND |  | J1
65 | 129 | DQ32 | D_D32 |  | J1
66 | 131 | DQ33 | D_D33 |  | J1
67 | 133 | Vss | GND |  | J1
68 | 135 | DQS4_N | D_DQS4_N |  | J1
69 | 137 | DQS4_P | D_DQS4_P |  | J1
70 | 139 | Vss | GND |  | J1
71 | 141 | DQ34 | D_D34 |  | J1
72 | 143 | DQ35 | D_D35 |  | J1
73 | 145 | Vss | GND |  | J1
74 | 147 | DQ40 | D_D40 |  | J1
75 | 149 | DQ41 | D_D41 |  | J1
76 | 151 | Vss | GND |  | J1
77 | 153 | DM5 | D_DM5 |  | J1
78 | 155 | Vss | GND |  | J1
79 | 157 | DQ42 | D_D42 |  | J1
80 | 159 | DQ43 | D_D43 |  | J1
81 | 161 | Vss | GND |  | J1
82 | 163 | DQ48 | D_D48 |  | J1
83 | 165 | DQ49 | D_D49 |  | J1
84 | 167 | Vss | GND |  | J1
85 | 169 | DQS6_N | D_DQS6_N |  | J1
86 | 171 | DQS6_P | D_DQS6_P |  | J1
87 | 173 | Vss | GND |  | J1
88 | 175 | DQ50 | D_D50 |  | J1
89 | 177 | DQ51 | D_D51 |  | J1
90 | 179 | Vss | GND |  | J1
91 | 181 | DQ56 | D_D56 |  | J1
92 | 183 | DQ57 | D_D57 |  | J1
93 | 185 | Vss | GND |  | J1
94 | 187 | DM7 | D_DM7 |  | J1
95 | 189 | Vss | GND |  | J1
96 | 191 | DQ58 | D_D58 |  | J1
97 | 193 | DQ59 | D_D59 |  | J1
98 | 195 | Vss | GND |  | J1
99 | 197 | SA0 | GND |  | J1
100 | 199 | Vddspd | VCC3V3 |  | J1
101 | 201 | SA1 | GND |  | J1
102 | 203 | Vtt | VTTDDR |  | J1
103 | 2 | Vss | GND |  | J1
104 | 4 | DQ4 | D_D4 |  | J1
105 | 6 | DQ5 | D_D5 |  | J1
106 | 8 | Vss | GND |  | J1
107 | 10 | DQS0_N | D_DQS0_N |  | J1
108 | 12 | DQS0_P | D_DQS0_P |  | J1
109 | 14 | Vss | GND |  | J1
110 | 16 | DQ6 | D_D6 |  | J1
111 | 18 | DQ7 | D_D7 |  | J1
112 | 20 | Vss | GND |  | J1
113 | 22 | DQ12 | D_D12 |  | J1
114 | 24 | DQ13 | D_D13 |  | J1
115 | 26 | Vss | GND |  | J1
116 | 28 | DM1 | D_DM1 |  | J1
117 | 30 | RESET_N | D_RESET_N |  | J1
118 | 32 | Vss | GND |  | J1
119 | 34 | DQ14 | D_D14 |  | J1
120 | 36 | DQ15 | D_D15 |  | J1
121 | 38 | Vss | GND |  | J1
122 | 40 | DQ20 | D_D20 |  | J1
123 | 42 | DQ21 | D_D21 |  | J1
124 | 44 | Vss | GND |  | J1
125 | 46 | DM2 | D_DM2 |  | J1
126 | 48 | Vss | GND |  | J1
127 | 50 | DQ22 | D_D22 |  | J1
128 | 52 | DQ23 | D_D23 |  | J1
129 | 54 | Vss | GND |  | J1
130 | 56 | DQ28 | D_D28 |  | J1
131 | 58 | DQ29 | D_D29 |  | J1
132 | 60 | Vss | GND |  | J1
133 | 62 | DQS3_N | D_DQS3_N |  | J1
134 | 64 | DQS3_P | D_DQS3_P |  | J1
135 | 66 | Vss | GND |  | J1
136 | 68 | DQ30 | D_D30 |  | J1
137 | 70 | DQ31 | D_D31 |  | J1
138 | 72 | Vss | GND |  | J1
139 | 74 | CKE1 | D_CKE1 |  | J1
140 | 76 | Vdd | VCC1V5_F |  | J1
141 | 78 | A15 | D_A15 |  | J1
142 | 80 | A14 | D_A14 |  | J1
143 | 82 | Vdd | VCC1V5_F |  | J1
144 | 84 | A11 | D_A11 |  | J1
145 | 86 | A7 | D_A7 |  | J1
146 | 88 | Vdd | VCC1V5_F |  | J1
147 | 90 | A6 | D_A6 |  | J1
148 | 92 | A4 | D_A4 |  | J1
149 | 94 | Vdd | VCC1V5_F |  | J1
150 | 96 | A2 | D_A2 |  | J1
151 | 98 | A0 | D_A0 |  | J1
152 | 100 | Vdd | VCC1V5_F |  | J1
153 | 102 | CK1_P | D_CLK1_P |  | J1
154 | 104 | CK1_N | C_CLK1_N |  | J1
155 | 106 | Vdd | VCC1V5_F |  | J1
156 | 108 | BA1 | D_BA1 |  | J1
157 | 110 | RAS_N | D_RAS_N |  | J1
158 | 112 | Vdd | VCC1V5_F |  | J1
159 | 114 | S0_N | D_SO_N |  | J1
160 | 116 | ODT0 | D_ODT0 |  | J1
161 | 118 | Vdd | VCC1V5_F |  | J1
162 | 120 | ODT1 | D_ODT1 |  | J1
163 | 122 | NC | NC |  | J1
164 | 124 | Vdd | VCC1V5_F |  | J1
165 | 126 | Vrefca | VTTVREF |  | J1
166 | 128 | Vss | GND |  | J1
167 | 130 | DQ36 | D_D36 |  | J1
168 | 132 | DQ37 | D_D37 |  | J1
169 | 134 | Vss | GND |  | J1
170 | 136 | DM4 | D_DM4 |  | J1
171 | 138 | Vss | GND |  | J1
172 | 140 | DQ38 | D_D38 |  | J1
173 | 142 | DQ39 | D_D39 |  | J1
174 | 144 | Vss | GND |  | J1
175 | 146 | DQ44 | D_D44 |  | J1
176 | 148 | DQ45 | D_D45 |  | J1
177 | 150 | Vss | GND |  | J1
178 | 152 | DQS5_N | D_DQS5_N |  | J1
179 | 154 | DQS5_P | D_DQS5_P |  | J1
180 | 156 | Vss | GND |  | J1
181 | 158 | DQ46 | D_D46 |  | J1
182 | 160 | DQ47 | D_D47 |  | J1
183 | 162 | Vss | GND |  | J1
184 | 164 | DQ52 | D_D52 |  | J1
185 | 166 | DQ53 | D_D53 |  | J1
186 | 168 | Vss | GND |  | J1
187 | 170 | DM6 | D_DM6 |  | J1
188 | 172 | Vss | GND |  | J1
189 | 174 | DQ54 | D_D54 |  | J1
190 | 176 | DQ55 | D_D55 |  | J1
191 | 178 | Vss | GND |  | J1
192 | 180 | DQ60 | D_D60 |  | J1
193 | 182 | DQ61 | D_D61 |  | J1
194 | 184 | Vss | GND |  | J1
195 | 186 | DQS7_N | D_DQS7_N |  | J1
196 | 188 | DQS7_P | D_DQS7_P |  | J1
197 | 190 | Vss | GND |  | J1
198 | 192 | DQ62 | D_D62 |  | J1
199 | 194 | DQ63 | D_D63 |  | J1
200 | 196 | Vss | GND |  | J1
201 | 198 | EVENT_N | D_TEMP_EVENT |  | J1
202 | 200 | SDA | IIC_SDA_D |  | J1
203 | 202 | SCL | IIC_SCL_D |  | J1
204 | 204 | Vtt | VTTDDR |  | J1
205 | A1 | RXD5 | P_RXD5 |  | U12
206 | A2 | RXD6 | P_RXD6 |  | U12
207 | A3 | S_IN_P | SGMII_TX_C_P |  | U12
208 | A4 | S_IN_N | SGMII_TX_C_N |  | U12
209 | A5 | S_CLK_P | NC |  | U12
210 | A6 | S_CLK_N | NC |  | U12
211 | A7 | S_OUT_P | SGMII_RX_C_P |  | U12
212 | A8 | S_OUT_N | SGMII_RX_C_N |  | U12
213 | A9 | LED_LINK1000 | P_LED_LINK1000 |  | U12
214 | B1 | RX_DV | P_RXCTL_RXDV |  | U12
215 | B2 | RXD0 | P_RXD0 |  | U12
216 | B3 | RXD3 | P_RXD3 |  | U12
217 | B4 | VDDO | VCC2V5 |  | U12
218 | B5 | CRS | P_CRS |  | U12
219 | B6 | COL | P_COL |  | U12
220 | B7 | AVDD | GND |  | U12
221 | B8 | LED_LINK100 | P_LED_LINK100 |  | U12
222 | B9 | VDDOH | VCC2V5 |  | U12
223 | C1 | RX_CLK | P_RXCLK |  | U12
224 | C2 | VDDO | VCC2V5 |  | U12
225 | C3 | RXD2 | P_RXD2 |  | U12
226 | C4 | RXD4 | P_RXD4 |  | U12
227 | C5 | RXD7 | P_RXD7 |  | U12
228 | C6 | DVDD | VCCINT |  | U12
229 | C7 | DVDD | VCCINT |  | U12
230 | C8 | LED_LINK10 | P_LED_LINK10 |  | U12
231 | C9 | LED_RX | P_LED_RX |  | U12
232 | D1 | TX_CLK | P_TXCLK |  | U12
233 | D2 | RX_ER | P_RXER |  | U12
234 | D3 | RXD1 | P_RXD1 |  | U12
235 | D4 | VSS | GND |  | U12
236 | D5 | VSS | GND |  | U12
237 | D6 | VSS | GND |  | U12
238 | D7 | DVDD | VCCINT |  | U12
239 | D8 | CONFIG_0 | P_CONFIG0 |  | U12
240 | D9 | LED_TX | P_LED_TX |  | U12
241 | E1 | TX_EN | P_TXCTL_TXEN |  | U12
242 | E2 | GTX_CLK | P_TXC_GTXCLK |  | U12
243 | E3 | DVDD | VCCINT |  | U12
244 | E4 | VSS | GND |  | U12
245 | E5 | VSS | GND |  | U12
246 | E6 | VSS | GND |  | U12
247 | E7 | DVDD | VCCINT |  | U12
248 | E8 | LED_DUPLEX | P_LED_DUPLEX |  | U12
249 | E9 | CONFIG_1 | GND |  | U12
250 | F1 | TXD0 | P_TXD0 |  | U12
251 | F2 | TX_ER | P_TXER |  | U12
252 | F3 | DVDD | VCCINT |  | U12
253 | F4 | VSS | GND |  | U12
254 | F5 | VSS | GND |  | U12
255 | F6 | VSS | GND |  | U12
256 | F7 | VDDOH | VCC2V5 |  | U12
257 | F8 | CONFIG_2 | VCC2V5 |  | U12
258 | F9 | CONFIG_4 | P_CONFIG4 |  | U12
259 | G1 | NC | NC |  | U12
260 | G2 | TXD1 | P_TXD1 |  | U12
261 | G3 | TXD2 | P_TXD2 |  | U12
262 | G4 | VSS | GND |  | U12
263 | G5 | VSS | GND |  | U12
264 | G6 | VSS | GND |  | U12
265 | G7 | CONFIG_3 | VCC2V5 |  | U12
266 | G8 | CONFIG_6 | P_LED_RX |  | U12
267 | G9 | CONFIG_5 | P_CONFIG5 |  | U12
268 | H1 | TXD4 | P_TXD4 |  | U12
269 | H2 | TXD3 | P_TXD3 |  | U12
270 | H3 | TXD5 | P_TXD5 |  | U12
271 | H4 | VSS | GND |  | U12
272 | H5 | VSS | GND |  | U12
273 | H6 | VSS | GND |  | U12
274 | H7 | VSSC | GND |  | U12
275 | H8 | SEL_OSC | NC |  | U12
276 | H9 | XTAL1 | XTAL1_25MHz_ENET |  | U12
277 | J1 | TXD6 | P_TXD6 |  | U12
278 | J2 | TXD7 | P_TXD7 |  | U12
279 | J3 | DVDD | VCCINT |  | U12
280 | J4 | VSS | GND |  | U12
281 | J5 | VSS | GND |  | U12
282 | J6 | VSS | GND |  | U12
283 | J7 | DVDD | VCCINT |  | U12
284 | J8 | VDDOH | VCC2V5 |  | U12
285 | J9 | XTAL2 | XTAL2_25MHz_ENET |  | U12
286 | K1 | VDDO | VCC2V5 |  | U12
287 | K2 | 125CLK | NC |  | U12
288 | K3 | RESET_N | P_RESET |  | U12
289 | K4 | VSS | GND |  | U12
290 | K5 | VSS | GND |  | U12
291 | K6 | VSS | GND |  | U12
292 | K7 | NC | NC |  | U12
293 | K8 | TD0 | NC |  | U12
294 | K9 | VDDOX | VCC2V5 |  | U12
295 | L1 | INT_N | P_INT_R |  | U12
296 | L2 | VDDOX | VCC2V5 |  | U12
297 | L3 | MDC | P_MDC |  | U12
298 | L4 | COMA | P_COMA |  | U12
299 | L5 | VSS | GND |  | U12
300 | L6 | VSS | GND |  | U12
301 | L7 | TDI | NC |  | U12
302 | L8 | TMS | NC |  | U12
303 | L9 | TCK | NC |  | U12
304 | M1 | MDIO_SDA | P_MDIO |  | U12
305 | M2 | RSET | P_RSET |  | U12
306 | M3 | AVDD | GND |  | U12
307 | M4 | AVDD | GND |  | U12
308 | M5 | HSDAC_P | NC |  | U12
309 | M6 | HSDAC_N | NC |  | U12
310 | M7 | AVDD | GND |  | U12
311 | M8 | AVDD | GND |  | U12
312 | M9 | TRST_N |  |  | U12
313 | N1 | MDI0_P | P_MDI0_P |  | U12
314 | N2 | MDI0_N | P_MDI0_N |  | U12
315 | N3 | MDI1_P | P_MDI1_P |  | U12
316 | N4 | MDI1_N | P_MDI1_N |  | U12
317 | N5 | AVDD | GND |  | U12
318 | N6 | MDI2_P | P_MDI2_P |  | U12
319 | N7 | MDI2_N | P_MDI2_N |  | U12
320 | N8 | MDI3_P | P_MDI3_P |  | U12
321 | N9 | MDI3_N | P_MDI3_N |  | U12
322 | A2 | NC | NC |  | U7
323 | A3 | NC | NC |  | U7
324 | A4 | NC | NC |  | U7
325 | A5 | NC | NC |  | U7
326 | B1 | NC | NC |  | U7
327 | B2 | C | F_CCLK |  | U7
328 | B3 | Vss | GND |  | U7
329 | B4 | Vcc | VCC3V3 |  | U7
330 | B5 | NC | NC |  | U7
331 | C1 | NC | NC |  | U7
332 | C2 | S_N | QSPI_IC_CS_N |  | U7
333 | C3 | NC | NC |  | U7
334 | C4 | DQ2_VPP_WP_N | F_D2_R |  | U7
335 | C5 | NC | NC |  | U7
336 | D1 | NC | NC |  | U7
337 | D2 | DQ1 | F_D1_R |  | U7
338 | D3 | DQ0 | F_D0_R |  | U7
339 | D4 | DQ3_HOLD_N | F_D3 |  | U7
340 | D5 | NC | NC |  | U7
341 | E1 | NC | NC |  | U7
342 | E2 | NC | NC |  | U7
343 | E3 | NC | NC |  | U7
344 | E4 | NC | NC |  | U7
345 | E5 | NC | NC |  | U7
346 | 1 | A0 | GND |  | U6
347 | 2 | A1 | GND |  | U6
348 | 3 | A2 |  |  | U6
349 | 4 | GND | GND |  | U6
350 | 5 | SDA | EEPROM_IIC_SDA |  | U6
351 | 6 | SCL | EEPROM_IIC_SCL |  | U6
352 | 7 | WP | GND |  | U6
353 | 8 | VCC | VCC3V3 |  | U6
354 | 1 | GND | GND |  | U26
355 | 2 | TCK | J_TCK |  | U26
356 | 3 | TDI | J_TDI |  | U26
357 | 4 | TMS | J_TMS |  | U26
358 | 5 | GPIO0 | NC |  | U26
359 | 6 | GPIO1 | NC |  | U26
360 | 7 | GPIO2 | NC |  | U26
361 | 8 | TDO | J_TDO |  | U26
362 | 9 | VREF | VCC3V3 |  | U26
363 | 10 | GND | GND |  | U26
364 | 11 | 3V3 | VCC3V3 |  | U26
365 | 1 | TD0_P | P_MDI0_P |  | P4
366 | 2 | TD0_N | P_MDI0_N |  | P4
367 | 3 | TD1_P | P_MDI1_P |  | P4
368 | 4 | TD1_N | P_MDI1_N |  | P4
369 | 5 | TD2_P | P_MDI2_P |  | P4
370 | 6 | TD2_N | P_MDI2_N |  | P4
371 | 7 | TD3_P | P_MDI3_P |  | P4
372 | 8 | TD3_N | P_MDI3_N |  | P4
373 | 9 | VCC | VCC1V8_FILT |  | P4
374 | 10 | GND | GND |  | P4
375 | SH1 | SH1 |  |  | P4
376 | SH2 | SH2 |  |  | P4
377 | 1 | CD_DAT3 | SDIO_CD_DAT3 |  | U29
378 | 2 | CMD | SDIO_CMD |  | U29
379 | 3 | VSS1 | GND |  | U29
380 | 4 | VDD | VCC3V3 |  | U29
381 | 5 | CLK | SDIO_CLK |  | U29
382 | 6 | VSS2 | GND |  | U29
383 | 7 | DAT0 | SDIO_DAT0 |  | U29
384 | 8 | DAT1 | SDIO_DAT1 |  | U29
385 | 9 | DAT2 | SDIO_DAT2 |  | U29
386 | 10 | DETECT | SDIO_SDDET |  | U29
387 | 11 | PROTECT | SDIO_SDWP |  | U29
388 | 12 | DETECT_PROTECT | GND |  | U29
389 | 13 | GNDTAB1 | GND |  | U29
390 | 14 | GNDTAB2 | GND |  | U29
391 | 15 | GNDTAB3 | GND |  | U29
392 | 16 | GNDTAB4 | GND |  | U29
393 | 17 | IOGND1 | GND |  | U29
394 | 18 | IOGND2 | GND |  | U29
395 | 1 | 12V | VCC12_P_IN |  | J49
396 | 4 | 12V | VCC12_P_IN |  | J49
397 | 2 | NC | NC |  | J49
398 | 5 | NC | NC |  | J49
399 | 3 | COM | GND |  | J49
400 | 6 | COM | GND |  | J49
401 | 1 | NC | NC |  | U34
402 | 2 | OE | R15 |  | U34
403 | 3 | GND | GND |  | U34
404 | 4 | OUT | USER_CLOCK_P |  | U34
405 | 5 | OUT | USER_CLOCK_N |  | U34
406 | 6 | VDD | VCC3V3 |  | U34
407 | 7 | SDA | USER_CLOCK_SDA |  | U34
408 | 8 | SCL | USER_CLOCK_SCL |  | U34
409 | 1 | OE | VCC2V5 |  | U51
410 | 2 | NC | NC |  | U51
411 | 3 | GND | GND |  | U51
412 | 4 | OUT | SYSCLK_P |  | U51
413 | 5 | OUT_B | SYSCLK_N |  | U51
414 | 6 | VCC | VCC2V5 |  | U51
415 | 1 | VDDA | VDDA_EPHYCLK |  | U2
416 | 2 | GND | GND |  | U2
417 | 3 | XTAL_OUT | EPHYCLK_XTAL_OUT |  | U2
418 | 4 | XTAL_IN | EPHYCLK_XTAL_IN |  | U2
419 | 5 | OE | VDD_EPHYCLK |  | U2
420 | 6 | NQO | EPHYCLK_Q0_C_N |  | U2
421 | 7 | QO | EPHYCLK_Q0_C_P |  | U2
422 | 8 | VDD | VDD_EPHYCLK |  | U2
423 | 1 | OE1_N | GND |  | U19
424 | 2 | A1 | GND |  | U19
425 | 3 | A2 | JTAG_TDI |  | U19
426 | 4 | A3 | JTAG_TMS |  | U19
427 | 5 | A4 | NC |  | U19
428 | 6 | A5 | JTAG_TCK |  | U19
429 | 7 | A6 | NC |  | U19
430 | 8 | A7 | NC |  | U19
431 | 9 | A8 | NC |  | U19
432 | 10 | GND | GND |  | U19
433 | 11 | Y8 | NC |  | U19
434 | 12 | Y7 | NC |  | U19
435 | 13 | Y6 | NC |  | U19
436 | 14 | Y5 | FPGA_TCK_BUF |  | U19
437 | 15 | Y4 | NC |  | U19
438 | 16 | Y3 | FPGA_TMS_BUF |  | U19
439 | 17 | Y2 | NC |  | U19
440 | 18 | Y1 | FPGA_TDI_BUF |  | U19
441 | 19 | OE2_N | GND |  | U19
442 | 20 | VCC | VCC3V3 |  | U19
443 | 1 | SD0 | USER_CLOCK_SDA |  | U52
444 | 2 | SC0 | USER_CLOCK_SCL |  | U52
445 | 3 | SD1 | NC |  | U52
446 | 4 | SC1 | NC |  | U52
447 | 5 | SD2 | EEPROM_IIC_SDA |  | U52
448 | 6 | SC2 | EEPROM_IIC_SCL |  | U52
449 | 7 | SD3 | NC |  | U52
450 | 8 | SC3 | NC |  | U52
451 | 9 | GND | GND |  | U52
452 | 10 | SD4 | NC |  | U52
453 | 11 | SC4 | NC |  | U52
454 | 12 | SD5 | NC |  | U52
455 | 13 | SC5 | NC |  | U52
456 | 14 | SD6 | IIC_SDA_DDR3 |  | U52
457 | 15 | SC6 | IIC_SCL_DDR3 |  | U52
458 | 16 | SD7 | SI5324_SDA |  | U52
459 | 17 | SC7 | SI5324_SCL |  | U52
460 | 18 | A2 | R56 |  | U52
461 | 19 | SCL | IIC_SCL_MAIN |  | U52
462 | 20 | SDA | IIC_SDA_MAIN |  | U52
463 | 21 | VCC | VCC3V3 |  | U52
464 | 22 | A0 | R242 |  | U52
465 | 23 | A1 | R243 |  | U52
466 | 24 | RESET_B | IIC_MUX_RESET_B |  | U52
467 | 25 | THERMPAD | GND |  | U52
468 | 1 | VCCA | VCC3V3 |  | U66
469 | 2 | GND | GND |  | U66
470 | 3 | A | R306/R307 |  | U66
471 | 4 | B | FPGA_INIT_B |  | U66
472 | 5 | DIR | GND |  | U66
473 | 6 | VCCB | FPGA_3V3 |  | U66
474
475
476
477
478
479
480
481
482
483
484
485
486
487
488
489
490
491
492
493
494
495
496
497
498
499
500
501
502
503
504
505
506
507
508
509
510
511
512
513
514
515
516
517
518
519
520
521
522
523
524
525
526
527
528
529
530
531
532
533
534
535
536
537
538
539
540
541
542
543
544
545
546
547
548
549
550
551
552
553
554
555
556
557
558
559
560
561
562
563
564
565
566
567
568
569
570
571
572
573
574
575
576
577
578
579
580
581
582
583
584
585
586
587
588
589
590
591
592
593
594
595
596
597
598
599
600
601
602
603
604
605
606
607
608
609
610
611

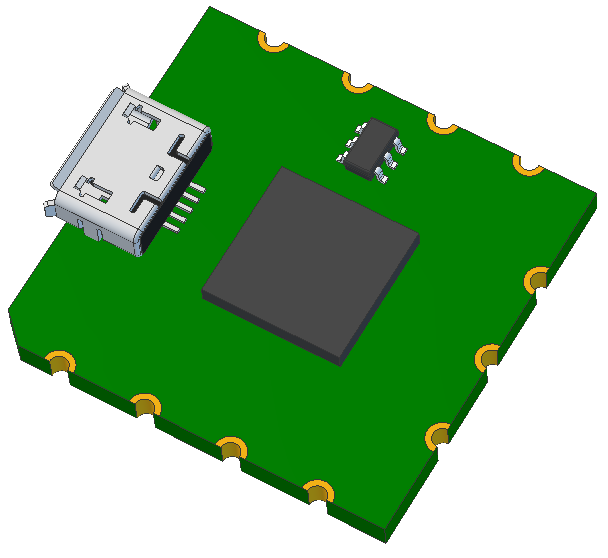
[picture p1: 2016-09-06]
parts/scratch/other/SMT2_1_0.PNG

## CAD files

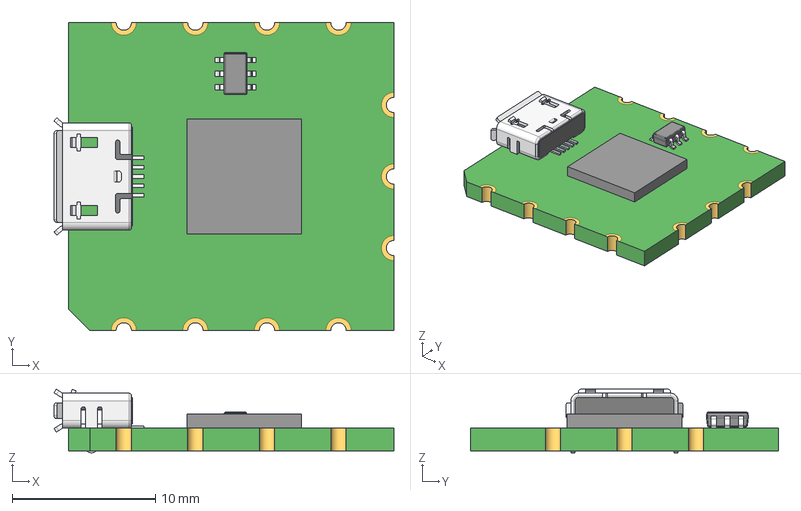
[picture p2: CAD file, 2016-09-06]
parts/scratch/other/SMT2_1_0.stp
23.8 x 21.5 x 4.45 mm

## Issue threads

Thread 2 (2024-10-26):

FPGA board inquiry

ztachip, 2024-10-26:
Do you sell these boards? And how much? And how do I buy it?
How your board different from AC701 since you said you base the design on AC701
AC701 seems to advertise for 1GB SODIMM only, not clear if the default memory module of 1GB can be swapped for 4GB
Your specs says your board supports 4GB SODIMM, and this is the key feature I am looking for.

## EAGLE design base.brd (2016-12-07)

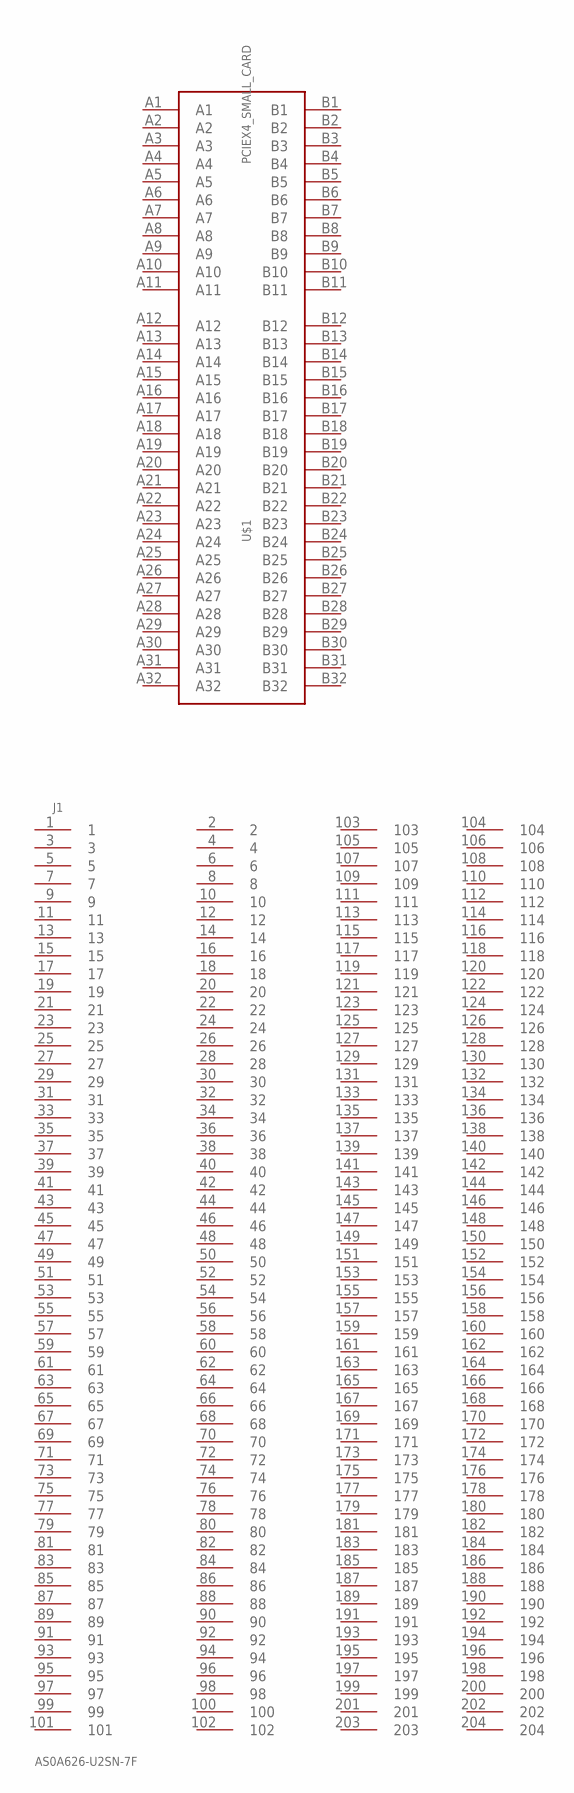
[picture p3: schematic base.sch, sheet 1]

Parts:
J1: AS0A626-U2SN-7F; FOXCONN_AS0A626-U2SN-7F
U$1: PCIEX4_SMALL_CARD

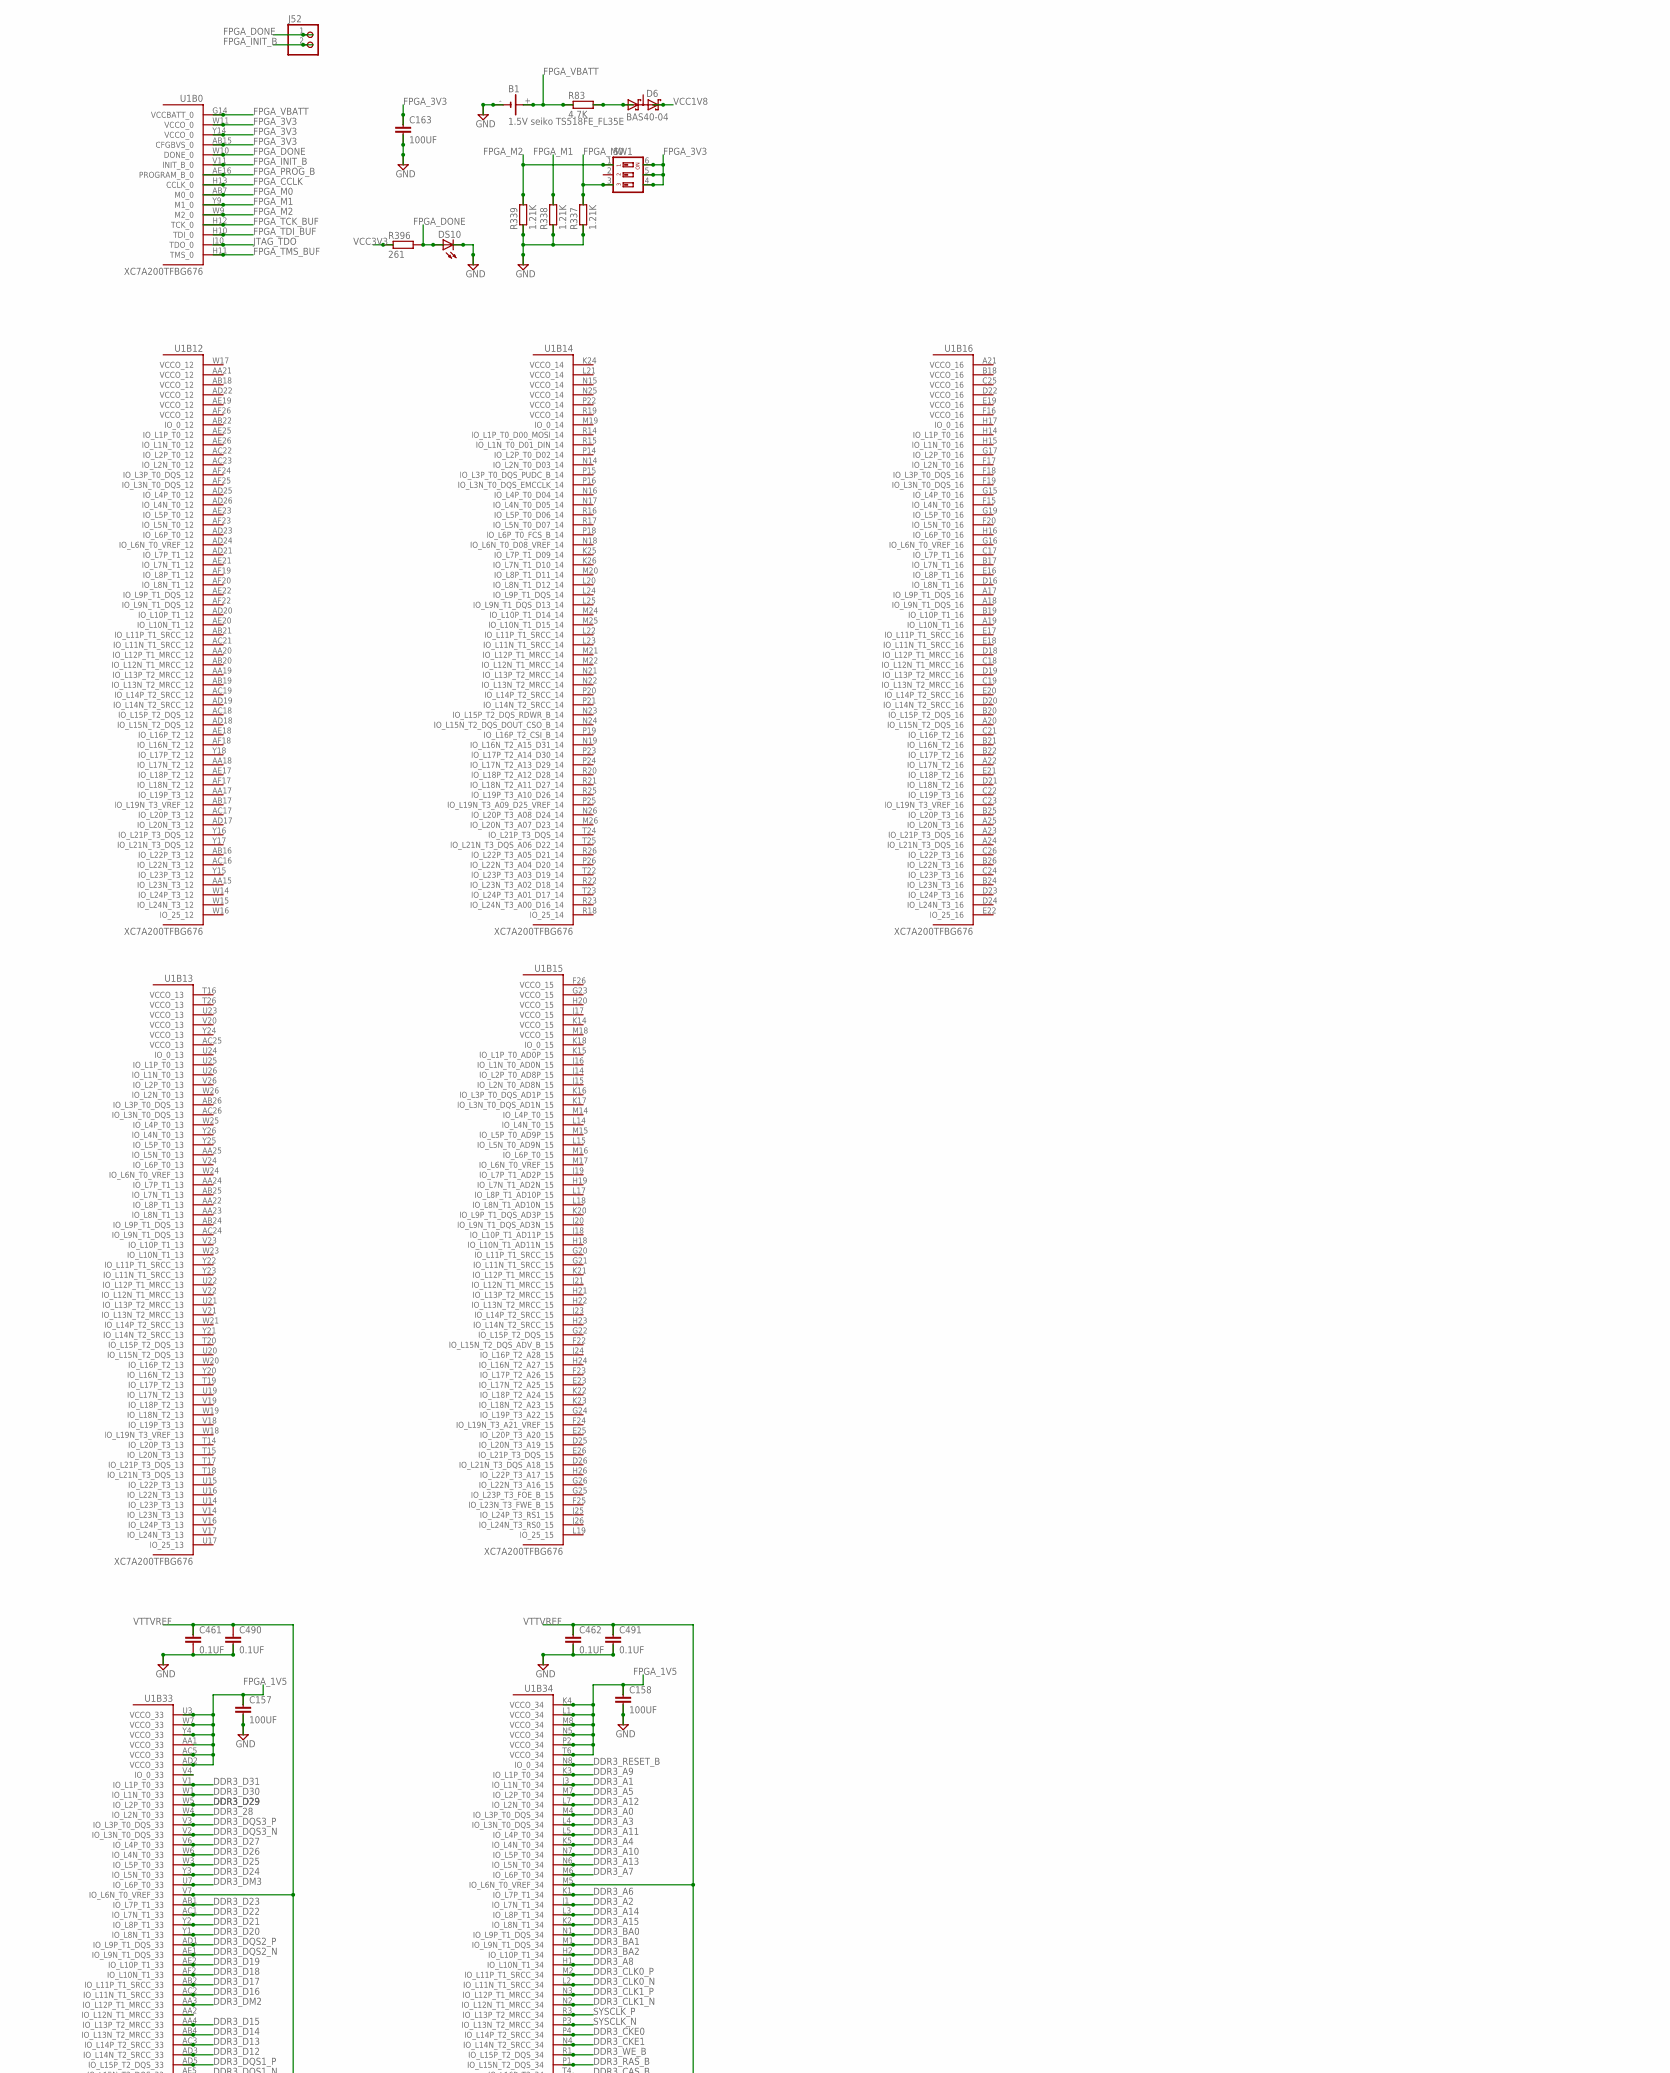
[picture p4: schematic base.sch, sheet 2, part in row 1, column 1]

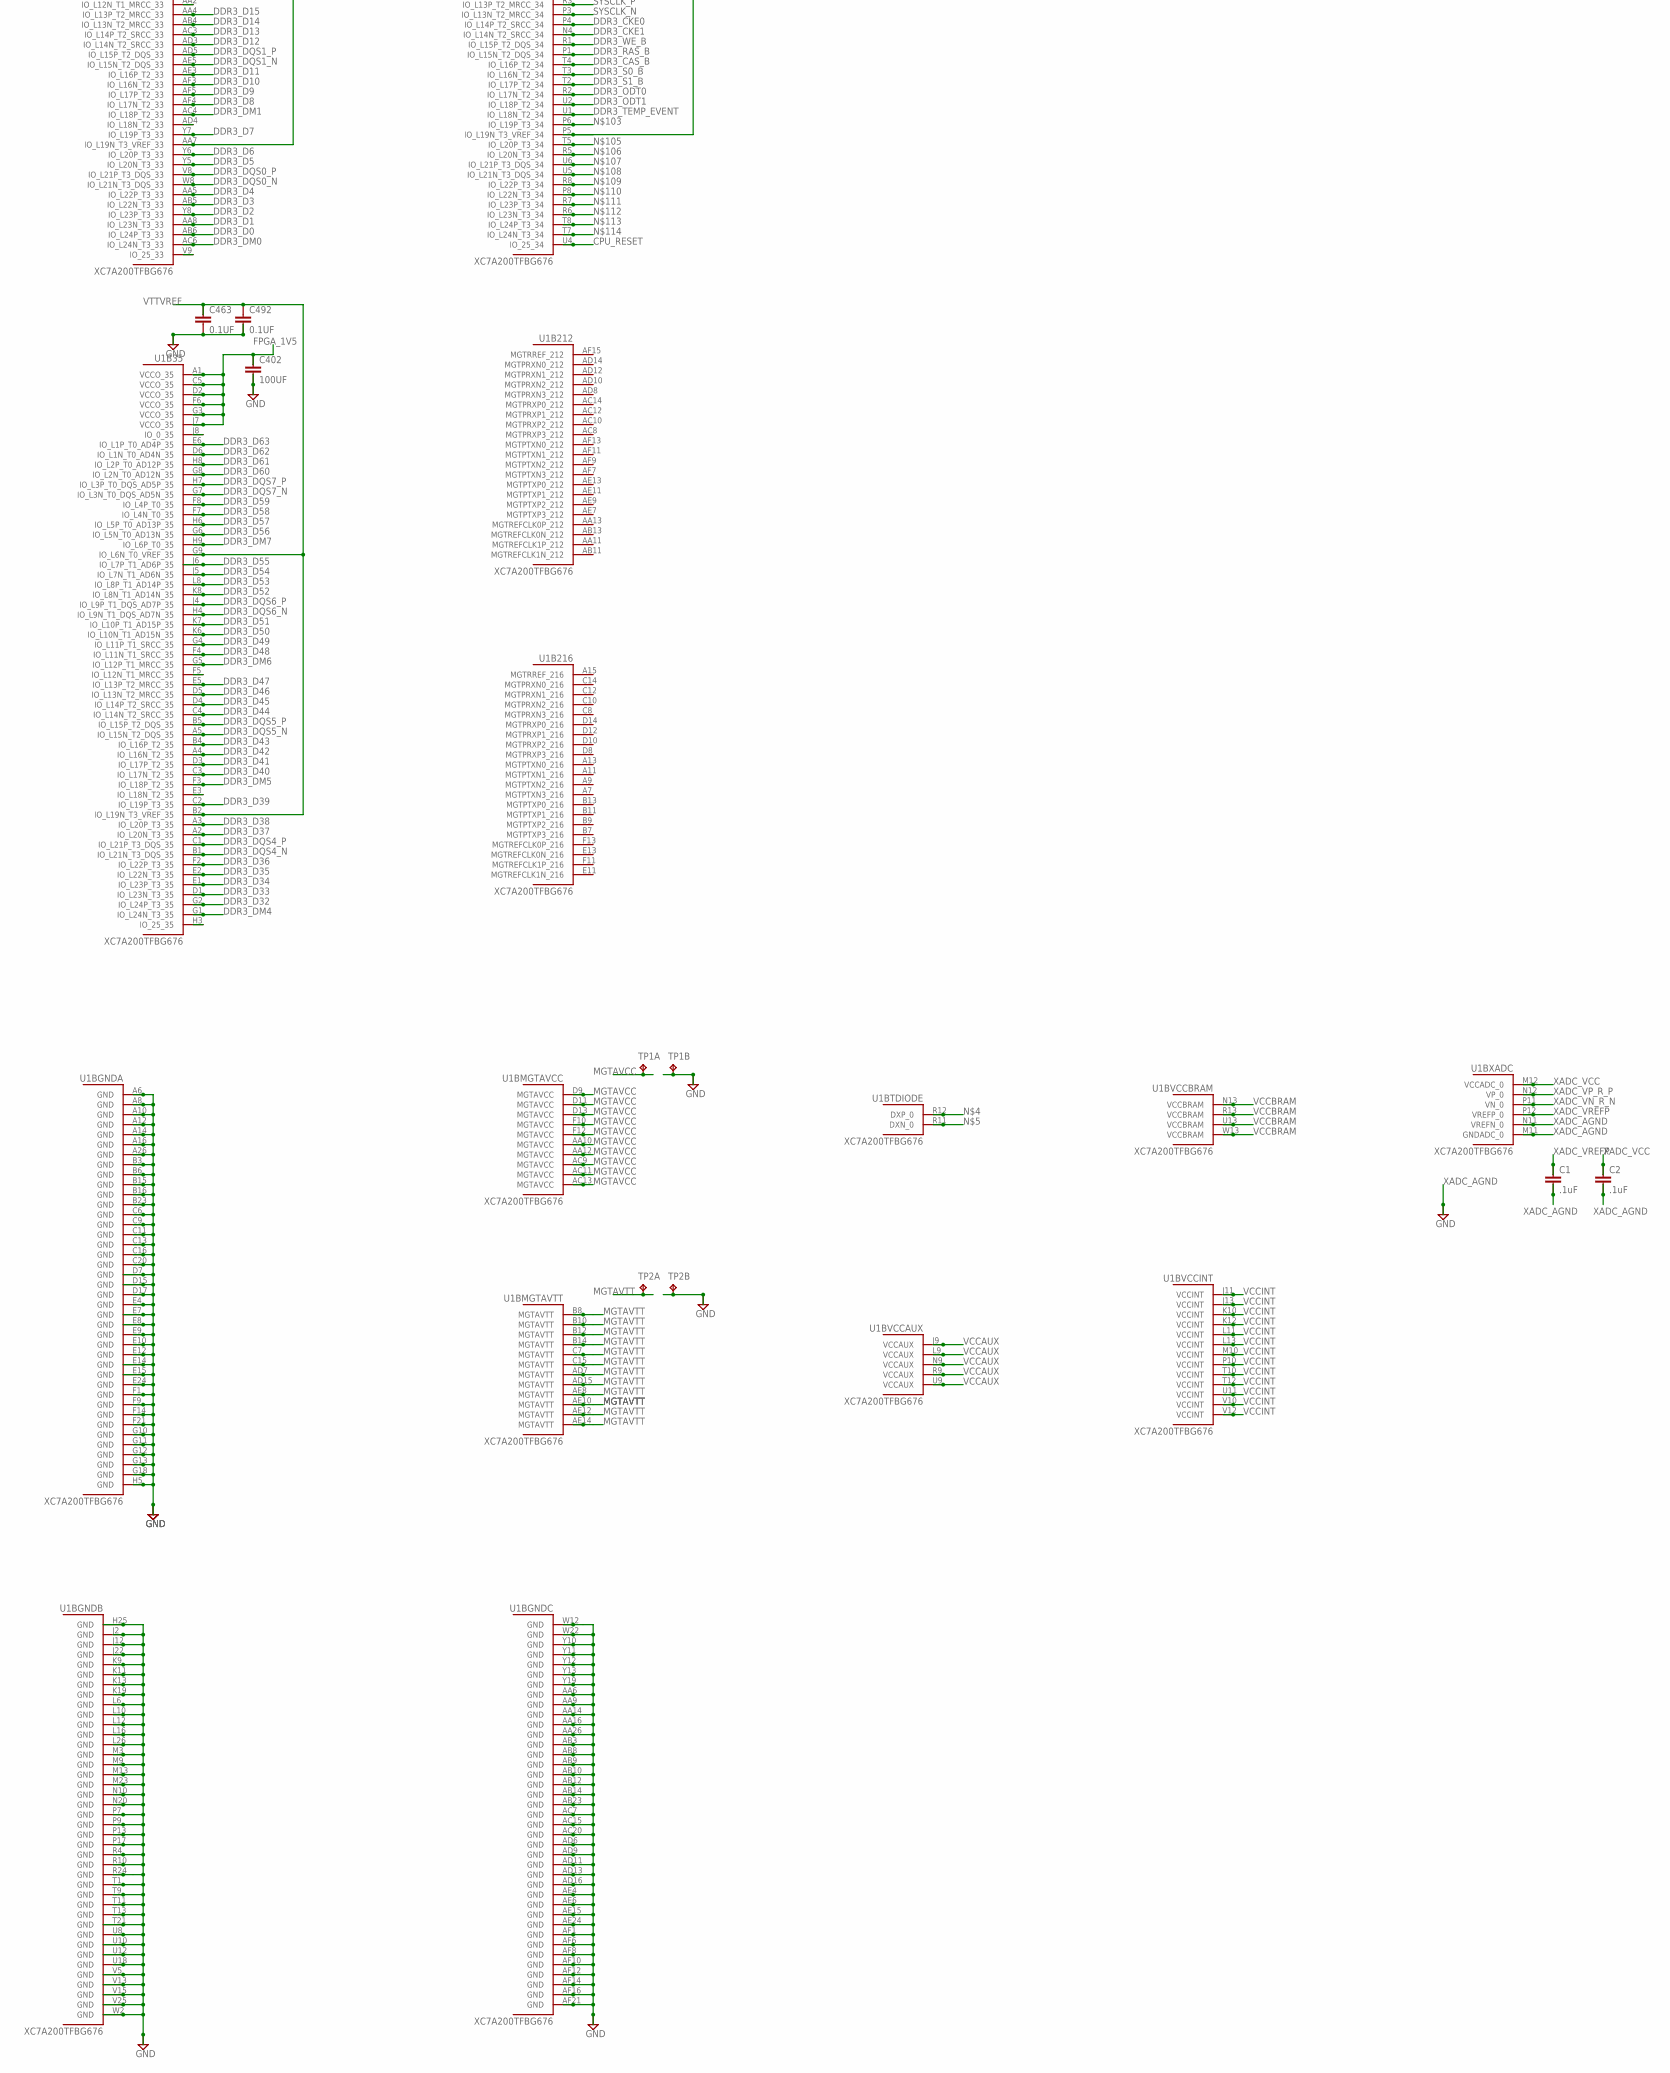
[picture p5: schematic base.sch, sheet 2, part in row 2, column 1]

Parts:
B1: 1.5V seiko TS518FE_FL35E; CH291-1220LF
C1, C2: .1uF; C0402
C157, C158, C163, C402: 100UF; C1206
C461, C462, C463, C490, C491, C492: 0.1UF; C0402
D6: BAS40-04; SOT23
DS10: LEDCHIP-LED0603; CHIP-LED0603
J52: PINHD-1X2; 1X02
R83: 4.7K; R0402
R337, R338, R339: 1.21K; R0402
R396: 261; R0402
SW1: SWS003; SMS-003
TP1, TP2: TP2P2-38-17; P2-38-17
U1: XC7A200TFBG676; FF676

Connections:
CPU_RESET: U1.U4 (IO_25_34)
DDR3_28: U1.W4 (IO_L2N_T0_33)
DDR3_A0: U1.M4 (IO_L3P_T0_DQS_34)
DDR3_A1: U1.J3 (IO_L1N_T0_34)
DDR3_A2: U1.J1 (IO_L7N_T1_34)
DDR3_A3: U1.L4 (IO_L3N_T0_DQS_34)
DDR3_A4: U1.K5 (IO_L4N_T0_34)
DDR3_A5: U1.M7 (IO_L2P_T0_34)
DDR3_A6: U1.K1 (IO_L7P_T1_34)
DDR3_A7: U1.M6 (IO_L6P_T0_34)
DDR3_A8: U1.H1 (IO_L10N_T1_34)
DDR3_A9: U1.K3 (IO_L1P_T0_34)
DDR3_A10: U1.N7 (IO_L5P_T0_34)
DDR3_A11: U1.L5 (IO_L4P_T0_34)
DDR3_A12: U1.L7 (IO_L2N_T0_34)
DDR3_A13: U1.N6 (IO_L5N_T0_34)
DDR3_A14: U1.L3 (IO_L8P_T1_34)
DDR3_A15: U1.K2 (IO_L8N_T1_34)
DDR3_BA0: U1.N1 (IO_L9P_T1_DQS_34)
DDR3_BA1: U1.M1 (IO_L9N_T1_DQS_34)
DDR3_BA2: U1.H2 (IO_L10P_T1_34)
DDR3_CAS_B: U1.T4 (IO_L16P_T2_34)
DDR3_CKE0: U1.P4 (IO_L14P_T2_SRCC_34)
DDR3_CKE1: U1.N4 (IO_L14N_T2_SRCC_34)
DDR3_CLK0_N: U1.L2 (IO_L11N_T1_SRCC_34)
DDR3_CLK0_P: U1.M2 (IO_L11P_T1_SRCC_34)
DDR3_CLK1_N: U1.N2 (IO_L12N_T1_MRCC_34)
DDR3_CLK1_P: U1.N3 (IO_L12P_T1_MRCC_34)
DDR3_D0: U1.AB6 (IO_L24P_T3_33)
DDR3_D1: U1.AA8 (IO_L23N_T3_33)
DDR3_D2: U1.Y8 (IO_L23P_T3_33)
DDR3_D3: U1.AB5 (IO_L22N_T3_33)
DDR3_D4: U1.AA5 (IO_L22P_T3_33)
DDR3_D5: U1.Y5 (IO_L20N_T3_33)
DDR3_D6: U1.Y6 (IO_L20P_T3_33)
DDR3_D7: U1.Y7 (IO_L19P_T3_33)
DDR3_D8: U1.AF4 (IO_L17N_T2_33)
DDR3_D9: U1.AF5 (IO_L17P_T2_33)
DDR3_D10: U1.AF3 (IO_L16N_T2_33)
DDR3_D11: U1.AE3 (IO_L16P_T2_33)
DDR3_D12: U1.AD3 (IO_L14N_T2_SRCC_33)
DDR3_D13: U1.AC3 (IO_L14P_T2_SRCC_33)
DDR3_D14: U1.AB4 (IO_L13N_T2_MRCC_33)
DDR3_D15: U1.AA4 (IO_L13P_T2_MRCC_33)
DDR3_D16: U1.AC2 (IO_L11N_T1_SRCC_33)
DDR3_D17: U1.AB2 (IO_L11P_T1_SRCC_33)
DDR3_D18: U1.AF2 (IO_L10N_T1_33)
DDR3_D19: U1.AE2 (IO_L10P_T1_33)
DDR3_D20: U1.Y1 (IO_L8N_T1_33)
DDR3_D21: U1.Y2 (IO_L8P_T1_33)
DDR3_D22: U1.AC1 (IO_L7N_T1_33)
DDR3_D23: U1.AB1 (IO_L7P_T1_33)
DDR3_D24: U1.Y3 (IO_L5N_T0_33)
DDR3_D25: U1.W3 (IO_L5P_T0_33)
DDR3_D26: U1.W6 (IO_L4N_T0_33)
DDR3_D27: U1.V6 (IO_L4P_T0_33)
DDR3_D29: U1.W5 (IO_L2P_T0_33)
DDR3_D30: U1.W1 (IO_L1N_T0_33)
DDR3_D31: U1.V1 (IO_L1P_T0_33)
DDR3_D32: U1.G2 (IO_L24P_T3_35)
DDR3_D33: U1.D1 (IO_L23N_T3_35)
DDR3_D34: U1.E1 (IO_L23P_T3_35)
DDR3_D35: U1.E2 (IO_L22N_T3_35)
DDR3_D36: U1.F2 (IO_L22P_T3_35)
DDR3_D37: U1.A2 (IO_L20N_T3_35)
DDR3_D38: U1.A3 (IO_L20P_T3_35)
DDR3_D39: U1.C2 (IO_L19P_T3_35)
DDR3_D40: U1.C3 (IO_L17N_T2_35)
DDR3_D41: U1.D3 (IO_L17P_T2_35)
DDR3_D42: U1.A4 (IO_L16N_T2_35)
DDR3_D43: U1.B4 (IO_L16P_T2_35)
DDR3_D44: U1.C4 (IO_L14N_T2_SRCC_35)
DDR3_D45: U1.D4 (IO_L14P_T2_SRCC_35)
DDR3_D46: U1.D5 (IO_L13N_T2_MRCC_35)
DDR3_D47: U1.E5 (IO_L13P_T2_MRCC_35)
DDR3_D48: U1.F4 (IO_L11N_T1_SRCC_35)
DDR3_D49: U1.G4 (IO_L11P_T1_SRCC_35)
DDR3_D50: U1.K6 (IO_L10N_T1_AD15N_35)
DDR3_D51: U1.K7 (IO_L10P_T1_AD15P_35)
DDR3_D52: U1.K8 (IO_L8N_T1_AD14N_35)
DDR3_D53: U1.L8 (IO_L8P_T1_AD14P_35)
DDR3_D54: U1.J5 (IO_L7N_T1_AD6N_35)
DDR3_D55: U1.J6 (IO_L7P_T1_AD6P_35)
DDR3_D56: U1.G6 (IO_L5N_T0_AD13N_35)
DDR3_D57: U1.H6 (IO_L5P_T0_AD13P_35)
DDR3_D58: U1.F7 (IO_L4N_T0_35)
DDR3_D59: U1.F8 (IO_L4P_T0_35)
DDR3_D60: U1.G8 (IO_L2N_T0_AD12N_35)
DDR3_D61: U1.H8 (IO_L2P_T0_AD12P_35)
DDR3_D62: U1.D6 (IO_L1N_T0_AD4N_35)
DDR3_D63: U1.E6 (IO_L1P_T0_AD4P_35)
DDR3_DM0: U1.AC6 (IO_L24N_T3_33)
DDR3_DM1: U1.AC4 (IO_L18P_T2_33)
DDR3_DM2: U1.AA3 (IO_L12P_T1_MRCC_33)
DDR3_DM3: U1.U7 (IO_L6P_T0_33)
DDR3_DM4: U1.G1 (IO_L24N_T3_35)
DDR3_DM5: U1.F3 (IO_L18P_T2_35)
DDR3_DM6: U1.G5 (IO_L12P_T1_MRCC_35)
DDR3_DM7: U1.H9 (IO_L6P_T0_35)
DDR3_DQS0_N: U1.W8 (IO_L21N_T3_DQS_33)
DDR3_DQS0_P: U1.V8 (IO_L21P_T3_DQS_33)
DDR3_DQS1_N: U1.AE5 (IO_L15N_T2_DQS_33)
DDR3_DQS1_P: U1.AD5 (IO_L15P_T2_DQS_33)
DDR3_DQS2_N: U1.AE1 (IO_L9N_T1_DQS_33)
DDR3_DQS2_P: U1.AD1 (IO_L9P_T1_DQS_33)
DDR3_DQS3_N: U1.V2 (IO_L3N_T0_DQS_33)
DDR3_DQS3_P: U1.V3 (IO_L3P_T0_DQS_33)
DDR3_DQS4_N: U1.B1 (IO_L21N_T3_DQS_35)
DDR3_DQS4_P: U1.C1 (IO_L21P_T3_DQS_35)
DDR3_DQS5_N: U1.A5 (IO_L15N_T2_DQS_35)
DDR3_DQS5_P: U1.B5 (IO_L15P_T2_DQS_35)
DDR3_DQS6_N: U1.H4 (IO_L9N_T1_DQS_AD7N_35)
DDR3_DQS6_P: U1.J4 (IO_L9P_T1_DQS_AD7P_35)
DDR3_DQS7_N: U1.G7 (IO_L3N_T0_DQS_AD5N_35)
DDR3_DQS7_P: U1.H7 (IO_L3P_T0_DQS_AD5P_35)
DDR3_ODT0: U1.R2 (IO_L17N_T2_34)
DDR3_ODT1: U1.U2 (IO_L18P_T2_34)
DDR3_RAS_B: U1.P1 (IO_L15N_T2_DQS_34)
DDR3_RESET_B: U1.N8 (IO_0_34)
DDR3_S0_B: U1.T3 (IO_L16N_T2_34)
DDR3_S1_B: U1.T2 (IO_L17P_T2_34)
DDR3_TEMP_EVENT: U1.U1 (IO_L18N_T2_34)
DDR3_WE_B: U1.R1 (IO_L15P_T2_DQS_34)
FPGA_1V5: C157.1, C158.1, C402.1, U1.AA1 (VCCO_33), U1.AC5 (VCCO_33), U1.AD2 (VCCO_33), U1.F6 (VCCO_35), U1.K4 (VCCO_34), U1.L1 (VCCO_34), U1.M8 (VCCO_34), U1.N5 (VCCO_34), U1.P2 (VCCO_34), U1.T6 (VCCO_34), U1.U3 (VCCO_33), U1.W7 (VCCO_33), U1.Y4 (VCCO_33)
FPGA_3V3: C163.1, SW1.4, SW1.5, SW1.6, U1.AB15 (CFGBVS_0), U1.W11 (VCCO_0), U1.Y14 (VCCO_0)
FPGA_CCLK: U1.H13 (CCLK_0)
FPGA_DONE: DS10.A, J52.1, R396.2, U1.W10 (DONE_0)
FPGA_INIT_B: J52.2, U1.V11 (INIT_B_0)
FPGA_M0: R337.2, SW1.3, U1.AB7 (M0_0)
FPGA_M1: R338.2, U1.Y9 (M1_0)
FPGA_M2: R339.2, SW1.1, U1.W9 (M2_0)
FPGA_PROG_B: U1.AE16 (PROGRAM_B_0)
FPGA_TCK_BUF: U1.H12 (TCK_0)
FPGA_TDI_BUF: U1.H10 (TDI_0)
FPGA_TMS_BUF: U1.H11 (TMS_0)
FPGA_VBATT: B1.+, R83.1, U1.G14 (VCCBATT_0)
GND: B1.-, C157.2, C158.2, C163.2, C402.2, C461.2, C462.2, C463.2, C490.2, C491.2, C492.2, DS10.C, R337.1, R338.1, R339.1, TP1.TP-2, TP2.TP-2, U1.A6 (GND), U1.A8 (GND), U1.A10 (GND), U1.A12 (GND), U1.A14 (GND), U1.A16 (GND), U1.A26 (GND), U1.AA6 (GND), U1.AA9 (GND), U1.AA14 (GND), U1.AA16 (GND), U1.AA26 (GND), U1.AB3 (GND), U1.AB8 (GND), U1.AB9 (GND), U1.AB10 (GND), U1.AB12 (GND), U1.AB14 (GND), U1.AB23 (GND), U1.AC7 (GND), U1.AC15 (GND), U1.AC20 (GND), U1.AD6 (GND), U1.AD9 (GND), U1.AD11 (GND), U1.AD13 (GND), U1.AD16 (GND), U1.AE4 (GND), U1.AE6 (GND), U1.AE15 (GND), U1.AE24 (GND), U1.AF1 (GND), U1.AF6 (GND), U1.AF8 (GND), U1.AF10 (GND), U1.AF12 (GND), U1.AF14 (GND), U1.AF16 (GND), U1.AF21 (GND), U1.B3 (GND), U1.B6 (GND), U1.B15 (GND), U1.B16 (GND), U1.B23 (GND), U1.C6 (GND), U1.C9 (GND), U1.C11 (GND), U1.C13 (GND), U1.C16 (GND), U1.C20 (GND), U1.D7 (GND), U1.D15 (GND), U1.D17 (GND), U1.E4 (GND), U1.E7 (GND), U1.E8 (GND), U1.E9 (GND), U1.E10 (GND), U1.E12 (GND), U1.E14 (GND), U1.E15 (GND), U1.E24 (GND), U1.F1 (GND), U1.F9 (GND), U1.F14 (GND), U1.F21 (GND), U1.G10 (GND), U1.G11 (GND), U1.G12 (GND), U1.G13 (GND), U1.G18 (GND), U1.H5 (GND), U1.H25 (GND), U1.J2 (GND), U1.J12 (GND), U1.J22 (GND), U1.K9 (GND), U1.K11 (GND), U1.K13 (GND), U1.K19 (GND), U1.L6 (GND), U1.L10 (GND), U1.L12 (GND), U1.L16 (GND), U1.L26 (GND), U1.M3 (GND), U1.M9 (GND), U1.M13 (GND), U1.M23 (GND), U1.N10 (GND), U1.N20 (GND), U1.P7 (GND), U1.P9 (GND), U1.P13 (GND), U1.P17 (GND), U1.R4 (GND), U1.R10 (GND), U1.R24 (GND), U1.T1 (GND), U1.T9 (GND), U1.T11 (GND), U1.T13 (GND), U1.T21 (GND), U1.U8 (GND), U1.U10 (GND), U1.U12 (GND), U1.U18 (GND), U1.V5 (GND), U1.V13 (GND), U1.V15 (GND), U1.V25 (GND), U1.W2 (GND), U1.W12 (GND), U1.W22 (GND), U1.Y10 (GND), U1.Y11 (GND), U1.Y12 (GND), U1.Y13 (GND), U1.Y19 (GND)
JTAG_TDO: U1.J10 (TDO_0)
MGTAVCC: TP1.TP-1, U1.AA10 (MGTAVCC), U1.AA12 (MGTAVCC), U1.AC9 (MGTAVCC), U1.AC11 (MGTAVCC), U1.AC13 (MGTAVCC), U1.D9 (MGTAVCC), U1.D11 (MGTAVCC), U1.D13 (MGTAVCC), U1.F10 (MGTAVCC), U1.F12 (MGTAVCC)
MGTAVTT: TP2.TP-1, U1.AD7 (MGTAVTT), U1.AD15 (MGTAVTT), U1.AE8 (MGTAVTT), U1.AE10 (MGTAVTT), U1.AE12 (MGTAVTT), U1.AE14 (MGTAVTT), U1.B8 (MGTAVTT), U1.B10 (MGTAVTT), U1.B12 (MGTAVTT), U1.B14 (MGTAVTT), U1.C7 (MGTAVTT), U1.C15 (MGTAVTT)
unnamed: D6.1 (A1), R83.2
SYSCLK_N: U1.P3 (IO_L13N_T2_MRCC_34)
SYSCLK_P: U1.R3 (IO_L13P_T2_MRCC_34)
VCC1V8: D6.2 (C2)
VCC3V3: R396.1
VCCAUX: U1.J9 (VCCAUX), U1.L9 (VCCAUX), U1.N9 (VCCAUX), U1.R9 (VCCAUX), U1.U9 (VCCAUX)
VCCBRAM: U1.N13 (VCCBRAM), U1.R13 (VCCBRAM), U1.U13 (VCCBRAM), U1.W13 (VCCBRAM)
VCCINT: U1.J11 (VCCINT), U1.J13 (VCCINT), U1.K10 (VCCINT), U1.K12 (VCCINT), U1.L11 (VCCINT), U1.L13 (VCCINT), U1.M10 (VCCINT), U1.P10 (VCCINT), U1.T10 (VCCINT), U1.T12 (VCCINT), U1.U11 (VCCINT), U1.V10 (VCCINT), U1.V12 (VCCINT)
VTTVREF: C461.1, C462.1, C463.1, C490.1, C491.1, C492.1, U1.AA7 (IO_L19N_T3_VREF_33), U1.B2 (IO_L19N_T3_VREF_35), U1.G9 (IO_L6N_T0_VREF_35), U1.M5 (IO_L6N_T0_VREF_34), U1.P5 (IO_L19N_T3_VREF_34), U1.V7 (IO_L6N_T0_VREF_33)
XADC_AGND: C1.2, C2.2, U1.M11 (GNDADC_0), U1.N11 (VREFN_0)
XADC_VCC: C2.1, U1.M12 (VCCADC_0)
XADC_VN_R_N: U1.P11 (VN_0)
XADC_VP_R_P: U1.N12 (VP_0)
XADC_VREFP: C1.1, U1.P12 (VREFP_0)

Board: 2 copper layers, 27 parts (0 on the bottom side), 19 nets, no tracks yet.

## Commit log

2016-09-03 adding base board and schematic for minimal kintex 160 fpga
    [base.brd, base.sch]
2016-09-04 adding DRAM.
    [base.brd, base.sch, bom.xlsx]
2016-09-04 updates to DRAM.
    [base.brd, base.sch]
2016-09-05 dram wired.
    [base.brd, base.sch]
2016-09-05 reverting dram, bigger chip.
    [base.brd, base.sch]
2016-09-06 Adding docs, adding pins, adding bom.
    [SMT2_1_0.stp, bom.xlsx, pins.xlsx]
2016-09-08 updating pins for sd, eeprom, flash, rj45.
    [bom.xlsx, pins.xlsx]
2016-09-09 updated with caps, resistors, inductors, and switches up to page 34
    [bom.xlsx, pins.xlsx]
2016-09-10 updated BOM and pin list
    [bom.xlsx, pins.xlsx]
2016-12-01 updating for new lib.
    [base.brd, base.sch]
2016-12-07 updates, wired 33 + 34
    [base.brd, base.sch]
2016-12-07 adding 35
    [base.brd, base.sch]
